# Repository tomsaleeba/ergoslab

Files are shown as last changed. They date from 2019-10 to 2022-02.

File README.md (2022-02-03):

> a columnar stagged keyboard that uses a combination of Cherry MX (or
> compatible) and Kailh choc switches to pack in a heap of thumb keys

*Update Dec 2020*: I've been using this keyboard full time (I'm a professional
software developer so it sees a lot of use) for a year now and I'm still in love
with it. If you're considering making one, I would call this design battle
proven now.

*Update Jan 2022*: Still using this full-time and loving it 💪.

- [What is this thing?](#what-is-this-thing)
- [Desgin choices:](#desgin-choices)
- [Build guide](#build-guide)
- [Gerbers](#gerbers)
- [Parts list](#parts-list)
  * [Parts you'll have to find yourself](#parts-youll-have-to-find-yourself)
  * [Parts available with PCB order](#parts-available-with-pcb-order)
- [Developers/contributing](#developerscontributing)
  * [Generating 3 layers of sandwich case](#generating-3-layers-of-sandwich-case)
  * [Generating gerbers](#generating-gerbers)
- [Credit for Kicad symbols/footprints](#credit-for-kicad-symbolsfootprints)
- [FAQ](#faq)

# What is this thing?
Before swapping to this keyboard, I had been using an ErgoDox Infinity and an EZ
as my daily drivers for quite a few years. I loved using them but I was looking
for something more compact and with more (easily accessible) thumb keys. There
are so many candidates
([here](https://docs.google.com/spreadsheets/d/19-rTWbp8SCKdZFByPZu3RT8NSF8vVddDe8WL6R6b1qQ/edit?usp=sharing),
[here](https://keebfol.io/), [here](https://golem.hu/boards/) and
[here](https://github.com/diimdeep/awesome-split-keyboards)) but none match
*exactly* what I want, so I decided build my own!

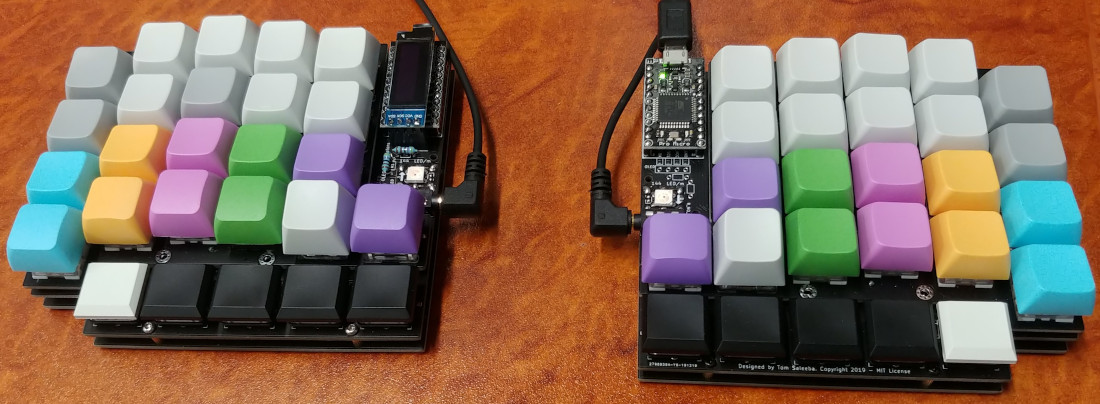
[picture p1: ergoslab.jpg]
ergoslab keyboard photo


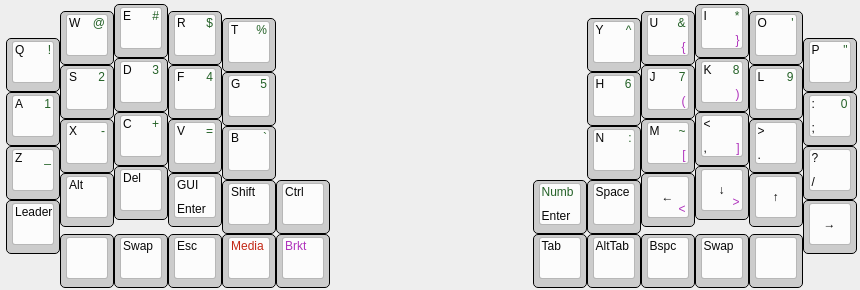
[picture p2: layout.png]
keyboard layout


# Desgin choices:
  - Kailh hotswap sockets for all the MX-style switches (choc are soldered in)
  - ErgoDox style ortho-columnar but with the extra little finger offset of the
      [Diverge 3](https://unikeyboard.io/product/diverge-3/)
  - Make all thumb keys easily accessible from the normal hand position
  - keys for vim-style arrows on the right hand, and directly below the home row
  - same plate design for both halves
  - compatible with QMK firmware, see [keyboard directory in QMK](https://github.com/qmk/qmk_firmware/tree/master/keyboards/ergoslab)
  - optional top LED for layer status ([example](./misc/layer-led-in-action.jpg))
  - optional underglow LEDs
  - minimise overall footprint by using internal standoffs (thanks for the idea
      [ErgoTravel](https://github.com/jpconstantineau/ErgoTravel))
  - use only 1U key caps to minimise size and because stabilisers are annoying
  - author a single "master" PCB and use a python script to generate the 3
      layers of the sandwich case. Makes life much easier to keep them all in
      sync. (See further down for more info)
  - support 5-pin/PCB mount switches

# Build guide
See the [guide here](./build-guide.md).

# Gerbers
See the [releases](https://github.com/tomsaleeba/ergoslab/releases) for this
GitHub repo for the generated Gerber files. You probably want the most recent
version.

If you need to generate your own gerbers, see [how to turn the master PCB into
the 3 generated PCBs](#generating-3-layers-of-sandwich-case) and then [how to
generate gerbers](#generating-gerbers).

# Parts list
## Parts you'll have to find yourself
  - 2x top PCBs (optional if you're happy with PCB mount; untested)
  - 2x middle PCBs (or 4x as they can also be used as the base)
  - 2x base PCBs (if you didn't order 4x middle)
  - 2x Pro Micros
  - 1x TRRS cable
  - 42x Cherry MX (or compatible) switches
  - 42x [Kailh hotswap PCB sockets](https://www.kailhswitch.com/mechanical-keyboard-switches/box-switches/mechanical-keyboard-switches-kailh-pcb-socket.html)
  - 10x Kailh choc switches
  - 42x 1U MX key caps
  - 10x 1U Kailh choc key caps
  - (optional) 2x WS2812 LED from a 144 LEDs/m strip, for layer status lights
  - (optional) more WS2812 LEDs, of any density per meter strip, for underglow
      lighting. 12x is probably a sane number but if you want to run them at
      lower power, you could probably use more.
  - 4x 15mm M2 standoffs (2 per side), for mounting the OLED/ProMicro acrylic cover
  - 8x M2 screws, between 4 and 8mm long, for the above standoffs
  - (optional) 1 or 2 OLED screens
  - 36x M2x4 screw (See Note1 and Note2) for mounting the middle/PCB layer to the base
      plate

**Note1**: the screw/bolt length depends on the height of the standoffs you get.
You want 1.6mm thick PCBs so make sure you don't have *too much* thread on your
screws.

**Note2**: it's highly recommended to get hex head/allen key/ISO7380 screws (see
image below). This is because a phillips head screwdriver probably won't fit
through the holes in the switch plate to tighten the screws on the middle/PCB
layer. You can always drill those holes a bit bigger or loctite the screws in
(so they won't need tighening) to workaround this. As you have hotswap sockets,
you may be able to remove the switches and pull the middle/PCB layer screws out
through the switch holes.  Beware: with 4mm long screws, I couldn't achieve
this, though it was very close.

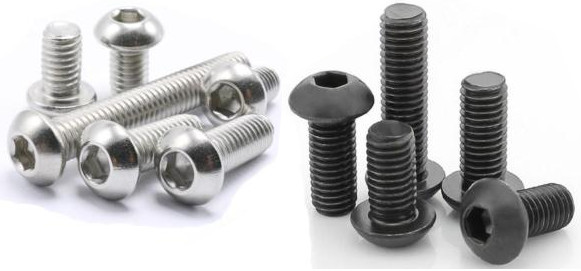
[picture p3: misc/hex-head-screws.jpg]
Photo of hex head screws


## Parts available with PCB order
These are the parts you can order from LCSC at the same time as having your PCBs
manufactured. The listed quantity is to assemble *both halves*.

| QTY |  Description |  LCSC Part No |
| :---: | :--- | :---: |
|0/2/4| 4.7KO (4701) ±1% (2 per OLED) |  [C58678](https://lcsc.com/product-detail/Metal-Film-Resistor-TH_4-7KR-4701-1_C58678.html) |
| 2  |  PJ-3200B-4A TRRS Connector |  [C136687](https://lcsc.com/product-detail/Audio-Video-Connectors_Korean-Hroparts-Elec-PJ-3200B-4A_C136687.html) |
| 2  |  Switch 5.2*5.2*1.5 reset switch |  [C92584](https://lcsc.com/product-detail/Tactile-Switches_Switch-5-2-5-2-1-5-250gf-Copper-head_C92584.html) |
| 2  |  2.54mm 1*40P round Female header |  [C9811](https://lcsc.com/product-detail/Female-Header_2-54mm-1-40P-round-Female-header_C9811.html) |
|0/1/2|  OLED Female header |  [C124413](https://lcsc.com/product-detail/Pin-Header-Female-Header_Ckmtw-Shenzhen-Cankemeng-C124413_C124413.html) |
| 52 |  1N4148 Switching Diode |  [C14516](https://lcsc.com/product-detail/Switching-Diode_1N4148_C14516.html) |
| 18 |  M2x6mm standoffs (See Note3) for middle/PCB layer to base plate mounting |  [M2x6](https://lcsc.com/product-detail/Studs_Made-in-China-Made-in-China-M2-6-3-5_C193468.html) |

**Note3**: the standoffs between the middle/PCB layer and the base plate can be
quite small, probably as small as 3mm. The problem with that is making sure the
bolts engage the threads enough. Feel free to experiment with getting a super
slim keyboard. Perhaps use a long bolt, a threadless spacer and a nut?

# Developers/contributing
Contributions are welcome. I'm not selling these keyboards and I already have
two for myself so I can't afford to manfacture more PCBs to test changes. If you
make changes to the PCB design, ideally you would confirm it all works by
manufacturing your own PCBs.

Steps for contributing:

1. if it's a non-trival change, consider opening an issue on this repo to talk
   about the change before spending effort
1. fork this repo
1. make your changes
1. if you made a change to the PCB, you need to [regenerate the 3 seperate
   generated PCBs](#generating-3-layers-of-sandwich-case)
1. send a pull request

## Generating 3 layers of sandwich case
We edit a single PCB file that contains the information required to generate all
3 layers (switch plate, circuitry, base) of a sandwich case keyboard. Keeping it
all in one file ensures that things like mounting holes always stay lined up.

There is some magic in the settings of items on the PCB to indicate what layer
they belong on. Read the code for the specifics but as a general guide:
  - we use Eco1.User as the templates for edge cuts that only appear on some
      layers
  - the width of the drawing lines are slightly different so we can determine
      which belongs on each layer
  - the thickness of text is slightly different so we can determine which
      belongs on each layer

You *must* have Kicad installed in your system. Doing this makes the `pcbnew`
python module available. Make sure you don't have any virtualenv, etc activated
as you need to be using you system-wide python. Check for the module by running
the following in the python REPL:

```python
import pcbnew
```

Now you can regenerate the PCBs with:

```bash
python ./generate_pcbs.py
```

Normally keeping generated things in source control is not a good idea but in
the interest of keeping things easy, we include the generated PCBs.

## Generating gerbers
Using KiCad 5.1.4, here's the settings to generate gerbers.

Plot settings (should be the defaults):
```
Plot format: Gerber
Included layers:
  F.Cu
  B.Cu
  F.Paste
  B.Paste
  F.SilkS
  B.SilkS
  F.Mask
  B.Mask
  Edge.Cuts
Plot foorprint values: yes
Plot footprint references: yes
Exclude PCB edge layer from other layers: yes
Exclude pads from silkscreen: yes
Default line width: 0.1mm
Coordinate format: 4.6, unit mm
```

Drill settings:
```
Drill File Format: Excellon
Mirror Y axis: no
Minimal header: no
PTH and NPTH in single file: no
Oval Holes Drill Mode: Use alternate drill mode
Map File Format: PostScript
Drill Origin: Absolute
Drill Units: Inches
Zeros Format: Suppress leading zeros
```

The fix for the JLCPCB PTH layer error was to change the [oval hole drill
mode](https://forum.kicad.info/t/jlcpcb-gives-me-warnings-on-drill-and-edge-cuts/17565/25).

# Credit for Kicad symbols/footprints
- [Kailh reversible footprints](https://github.com/daprice/keyswitches.pretty/blob/f89ef994a51043281f3fa6dfb4a93d8e4bebdbd1/Kailh_socket_reversible.kicad_mod) ([CC BY-SA](https://github.com/daprice/keyswitches.pretty/blob/f89ef994a51043281f3fa6dfb4a93d8e4bebdbd1/LICENSE.md))
- [P-08073 TACT reset switch footprint](https://github.com/kata0510/minisplit/blob/5fc4b23/minisplit-footprint.pretty/TACT_SWITCH_TVBP06.kicad_mod) ([MIT License](https://github.com/kata0510/minisplit/blob/5fc4b233df8120694ade5a3a812970439e8fc585/LICENSE))
- [symbols: TRRS jack, resistor](https://github.com/MakotoKurauchi/helix/tree/master/PCB/beta) (exported from schematic) ([MIT License](https://github.com/MakotoKurauchi/helix/blob/master/LICENSE))
- [LED symbol](https://github.com/tmk/kicad_lib_tmk) (no license)
- 2.54mm pin headers and diode footprints from built in Kicad library
- [footprints: 4 pin TACT reset, ProMicro, diode](https://github.com/jpconstantineau/ErgoTravel/tree/d443bf4/Library/footprints.pretty) ([MIT License](https://github.com/jpconstantineau/ErgoTravel/blob/master/LICENSE))

# FAQ
**How portable is it?**
It weighs 360grams (180grams for each half) with cheap DSA plastic keycaps. It
measures 115mm x 102mm and with 6mm standoffs, it's 16mm to the top of the
switch plate or 31mm to the top of DSA keycaps, including the height of rubber
bump-ons. I'll let you decide how portable you think that is but it was designed
to be portable.

**Is I2C between the halves supported?**
Sort of. The OLED screens use I2C so you won't be able to use them. Also there's
no solder jumpers so you'll have to jump some wires between the OLED header
SDA/SCL pins and the SLAVE_LED pin/data pin on the unused TRRS jack. This isn't
an intended use but you can certainly hack it, check the schematic for details.

**What happened to a single PCB that works as all 3 layers?**
Originally I tried to make one PCB design that works as all 3 layers of a
sandwich design: base, PCB and switch plate. The idea was taken from
[for-split-keyboard](https://github.com/peej/for-split-keyboard) and
[mitosis](https://www.reddit.com/r/MechanicalKeyboards/comments/66588f/wireless_split_qmk_mitosis/).
I failed because I wanted to have minimal post-manufacture cutting by hand and
JLCPCB kept rejecting my desgins as they didn't have strong enough supports to
hold the PCB together though the whole manufacture process. So now we have
"master" PCB design and use a python script to generate the PCBs for each layer
from that master.

**Do you have keyboard-layout-editor source?**\
Yes. Either [this file](./layout.kle) in this repo or here's a (hopefully up to date)
<a href="http://www.keyboard-layout-editor.com/##@@_x:3&t=#000000%0A%0A#115219;&=E%0A%0A#&_x:9.75&t=#000000%0A%0A#115219%0A#9914a6;&=I%0A%0A*%0A%7D;&@_y:-0.875&x:2&t=#000000%0A%0A#115219;&=W%0A%0A/@&_x:1;&=R%0A%0A$&_x:7.75&t=#000000%0A%0A#115219%0A#9914a6;&=U%0A%0A/&%0A%7B&_x:1&t=#000000%0A%0A#115219;&=O%0A%0A';&@_y:-0.875&x:5;&=T%0A%0A%25&_x:5.75;&=Y%0A%0A%5E;&@_y:-0.625&x:1;&=Q%0A%0A!&_x:13.75;&=P%0A%0A%22;&@_y:-0.625&x:3;&=D%0A%0A3&_x:9.75&t=#000000%0A%0A#115219%0A#9914a6;&=K%0A%0A8%0A);&@_y:-0.875&x:2&t=#000000%0A%0A#115219;&=S%0A%0A2&_x:1;&=F%0A%0A4&_x:7.75&t=#000000%0A%0A#115219%0A#9914a6;&=J%0A%0A7%0A(&_x:1&t=#000000%0A%0A#115219;&=L%0A%0A9;&@_y:-0.875&x:5;&=G%0A%0A5&_x:5.75;&=H%0A%0A6;&@_y:-0.625&x:1;&=A%0A%0A1&_x:13.75;&=/:%0A/;%0A0;&@_y:-0.625&x:3&t=#000000%0A#0b458a%0A#115219;&=C%0A%0A+&_x:9.75&t=#000000%0A%0A#115219%0A#9914a6;&=%3C%0A,%0A%0A%5D;&@_y:-0.875&x:2&t=#000000%0A#0b458a%0A#115219;&=X%0A%0A-&_x:1;&=V%0A%0A/=&_x:7.75&t=#000000%0A%0A#115219%0A#9914a6;&=M%0A%0A~%0A%5B&_x:1&t=#000000;&=%3E%0A.;&@_y:-0.875&x:5&t=#000000%0A%0A#115219;&=B%0A%0A%60&_x:5.75;&=N%0A%0A/:;&@_y:-0.625&x:1&t=#000000%0A#0b458a%0A#115219;&=Z%0A%0A/_&_x:13.75&t=#000000;&=?%0A//;&@_y:-0.625&x:3;&=Del&_x:9.75&t=#000000%0A%0A%0A#9914a6;&=%0A%0A%0A%3E%0A%0A%0A%0A%0A%0A%E2%86%93;&@_y:-0.875&x:2&t=#000000;&=Alt&_x:1;&=GUI%0AEnter&_x:7.75&t=#000000%0A%0A%0A#9914a6;&=%0A%0A%0A%3C%0A%0A%0A%0A%0A%0A%E2%86%90&_x:1&t=#000000&a:7;&=%E2%86%91;&@_y:-0.875&x:5&a:4;&=Shift&=Ctrl&_x:3.75&t=#115219;&=Numb%0AEnter&_t=#000000;&=Space;&@_y:-0.625&x:1;&=Leader&_x:13.75&a:7;&=%E2%86%92;&@_y:-0.375&x:2;&=&_a:4;&=Swap&_t=#000000%0A#0b458a;&=Esc&_t=#ab0202;&=Media&_t=#9914a6;&=Brkt&_x:3.75&t=#000000;&=Tab&=AltTab&=Bspc&=Swap&_a:7;&=">permalink</a>

**Do you have a vector of the right hand "plate"?**\
Yep, see [misc/ergoslab-right.svg](misc/ergoslab-right.svg).

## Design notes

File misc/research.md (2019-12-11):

## Answered questions
  1. can I get the same "only flash master" behaviour as the Ergodox EZ by
     using a [MCP23018-E/SP I/O expander](https://www.ergodox.io/#electronics)
     on the slave side? Yes, but it's not worth it as it'll be slow.
     [link](https://www.reddit.com/r/olkb/comments/bdchr5/hardware_options/el2b9s9/)
     [link](https://www.reddit.com/r/olkb/comments/a8y8mv/help_using_an_io_expander_with_qmk/ecro8p5/)
  1. do we need [pull up
     resistors](https://beta.docs.qmk.fm/features/feature_split_keyboard#required-hardware)
     for communication between the two halves? Only if you want to use I2C to
     communicate between the halves. If you're happy to use serial, then you
     don't use the resistors.
  1. do we need a blank space to rest thumbs? No, resting them on a switch works
     fine.
  1. from top of switch plate, we need 8.3mm for Kailh Box switches to clear the
     base plate. So including a 1.6mm thick base PCB and 1.75mm thick nut, we
     need at least 11.65mm long bolt that can sandwhich everything.
     Alternatively, we need at least 6.7mm of space *between* the switch and
     base plates.

## Facts
- MX switches are 5mm deep, Kailh choc are 2.35mm so the choc row should drop by
  2.65mm. The top of the choc switches will be ~5mm above the top of the
  switchplate for the MX switches.
- WS2812 strips are driven from any old pin, they don't use I2C
- ErgoDox style columnar staggered: 0, +1/4U (4.75mm), +3/8U (7.125mm), +1/4U
  (4.75mm), +1/8U (2.375mm)
- stabilising 4th/5th legs on Gateron switch: 1.575mm (as measured with
    micrometer)

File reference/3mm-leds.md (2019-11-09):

Bought from https://www.ebay.com.au/itm/Ultra-Bright-Clear-LEDs-3mm-or-5mm-Red-Yellow-Blue-Green-White-or-Mixed/192224975067

# 3mm Specifications.

Colour | Typical Voltage | Typical Current | Typical Brightness | Resistor @ 5V
-------|-----------------|-----------------|--------------------|--------------
Red    | 1.8-2.3V        | 20mA            | 4000-5000 mcd      | 82 - 100ohm
Yellow | 1.8-2.3V        | 20mA            | 2000-3000 mcd      | 82 - 100ohm
Blue   | 3.2-3.4V        | 20mA            | 3000-5000 mcd      | 150 - 180ohm
Green  | 3.2-3.4V        | 20mA            | 12000-20000 mcd    | 150 - 180ohm
White  | 3.2-3.4V        | 20mA            | 6000-8000 mcd      | 150 - 180ohm

Resistors calculated with http://led.linear1.org/1led.wiz

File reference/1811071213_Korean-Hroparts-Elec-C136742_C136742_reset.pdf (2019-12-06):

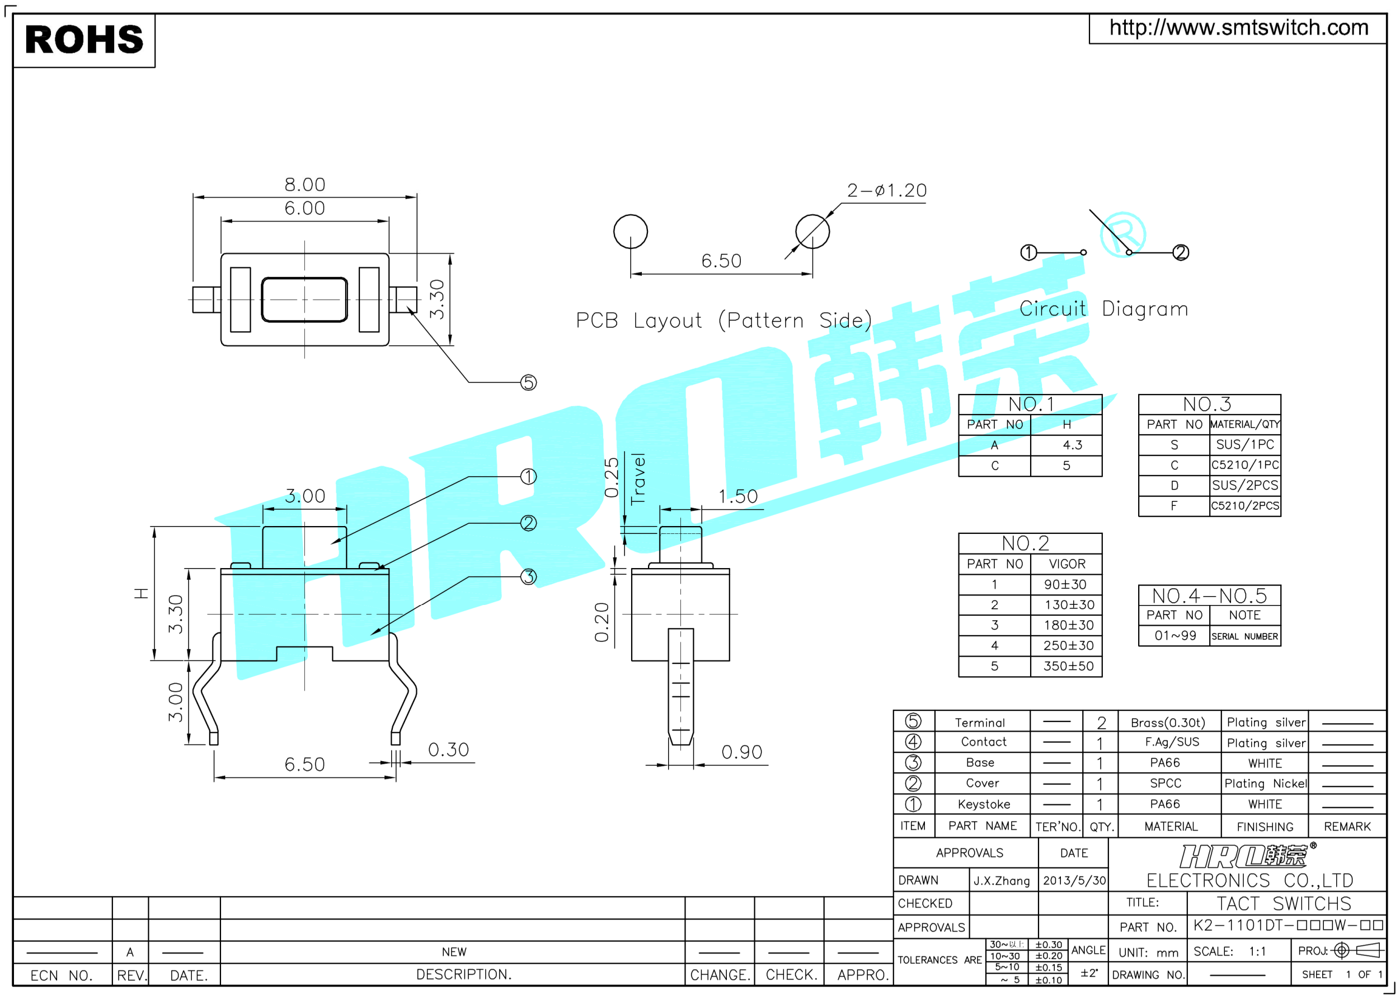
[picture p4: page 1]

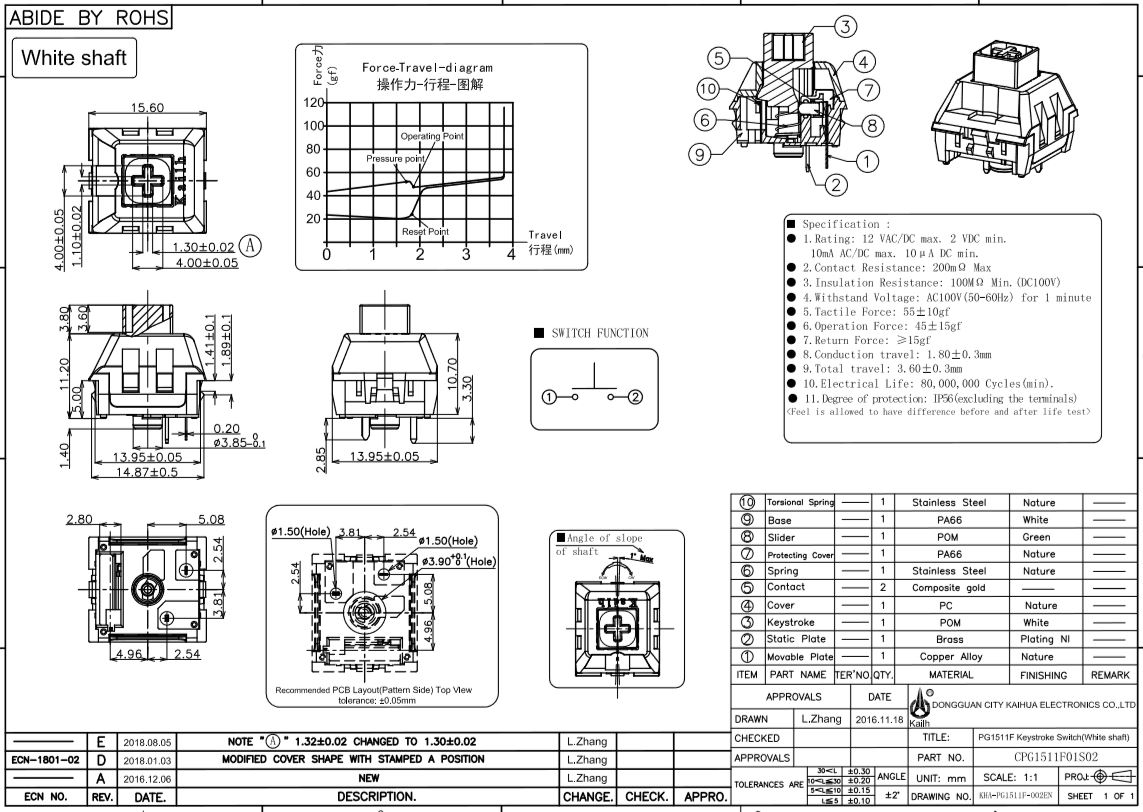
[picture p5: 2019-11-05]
reference/kailh-box-switch-specifications-NEW.jpg

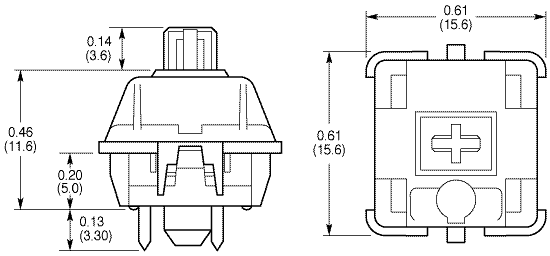
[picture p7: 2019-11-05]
reference/cherry-mx-specs.gif

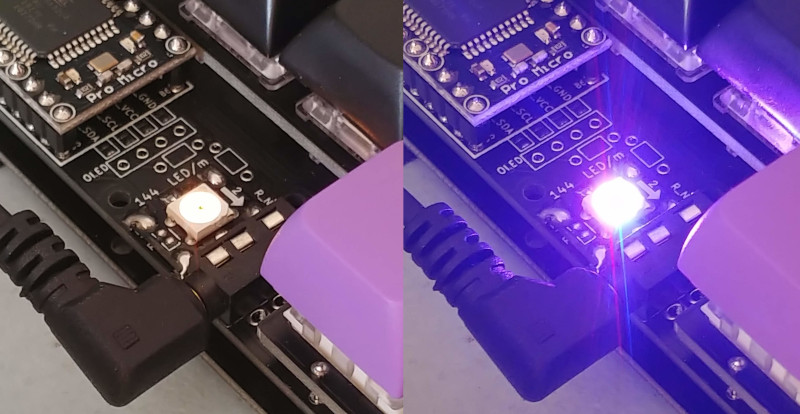
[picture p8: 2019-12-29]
misc/layer-led-in-action.jpg

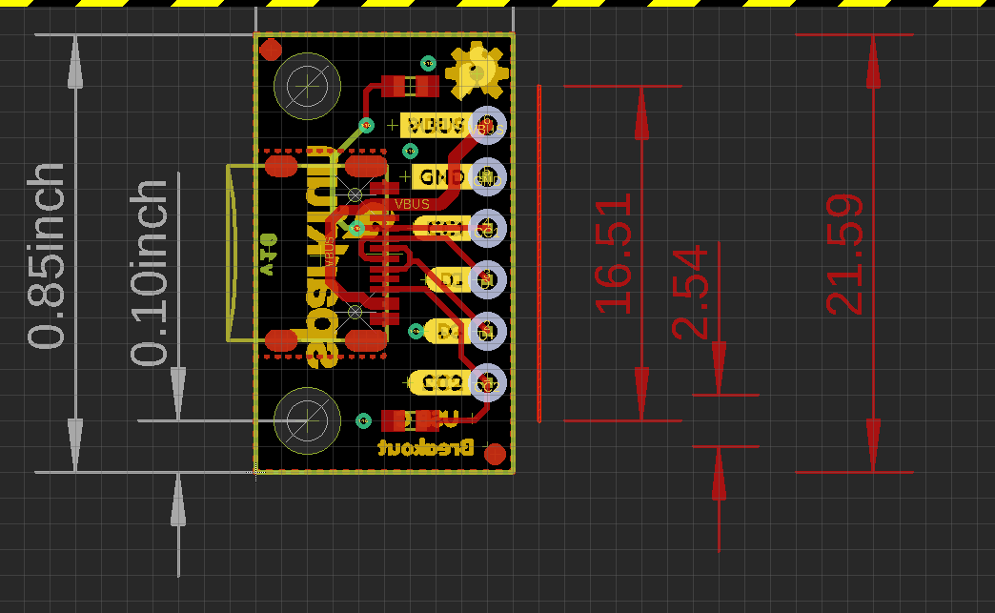
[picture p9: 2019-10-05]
misc/usb-c-breakout.png

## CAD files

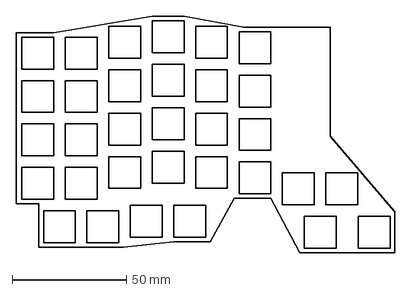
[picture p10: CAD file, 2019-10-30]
misc/test-layouts/helix-stagger/switchplate.dxf
166.2 x 103.7 mm

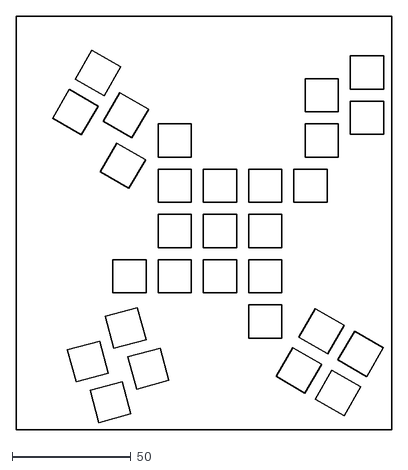
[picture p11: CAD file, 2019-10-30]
misc/test-layouts/throwing-star-thumb-tester/switchplate.dxf
157.9 x 174.3

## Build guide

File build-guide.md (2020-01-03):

# Steps
1. Install diodes. Place them over the silk screen markers so you don't cover
   the pads for the hotswap sockets. This means both sides will be the same and
   yes, you'll have diodes on the top and bottom of both halves.
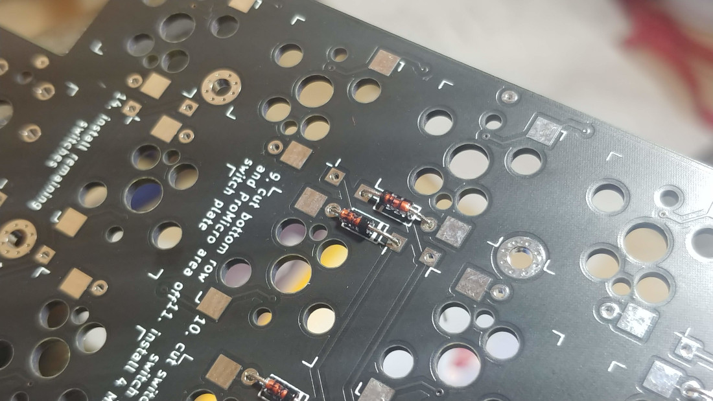
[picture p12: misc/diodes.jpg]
diodes
    
1. trim the diode legs but keep them as we'll need them later for the ProMicro
   pins (into the sockets) and for bracing the switchplate to the middle/PCB
   layer.
1. Install the reset switch. First tin one of the pads
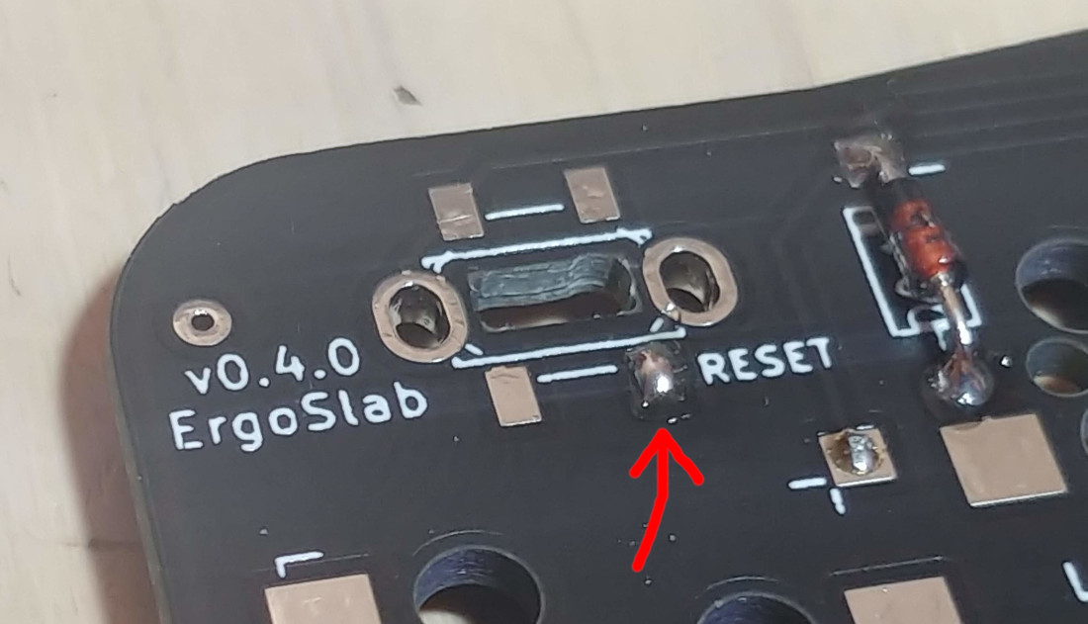
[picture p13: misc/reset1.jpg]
reset switch tinned pad
    
1. then reflow the tinned pad and solder a leg of the reset switch
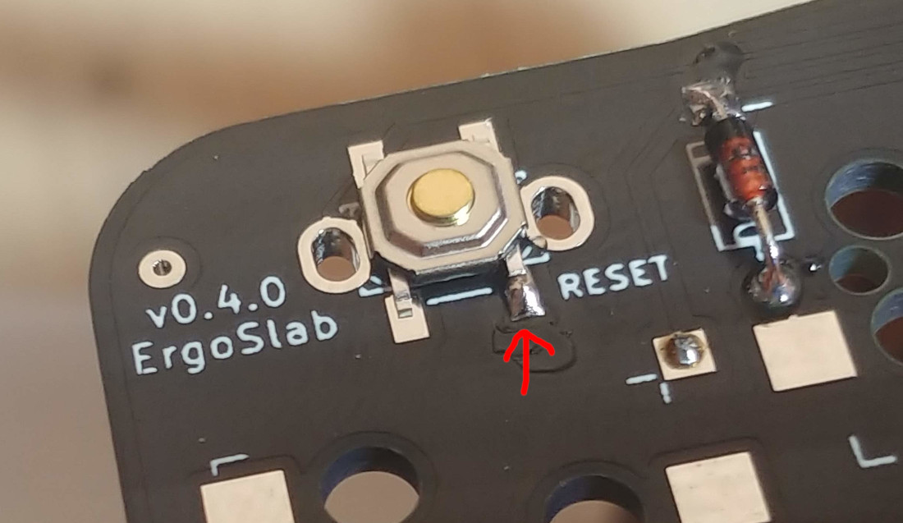
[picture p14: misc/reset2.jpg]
reset switch reflow leg
    
1. now you can solder the other legs
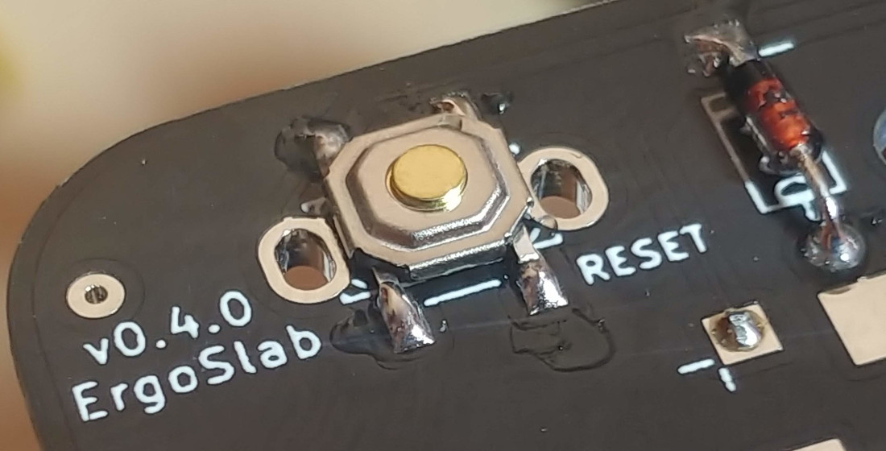
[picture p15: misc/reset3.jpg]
reset switch other legs
    
1. If you're using an LED on the top, install that now. Do the same trick as the
   reset switch where you tin one pad, reflow, then solder the other pads. The
   144 LEDs/m don't seem to have space to label the pads but on mine, the edge
   with the arrow is the GND.
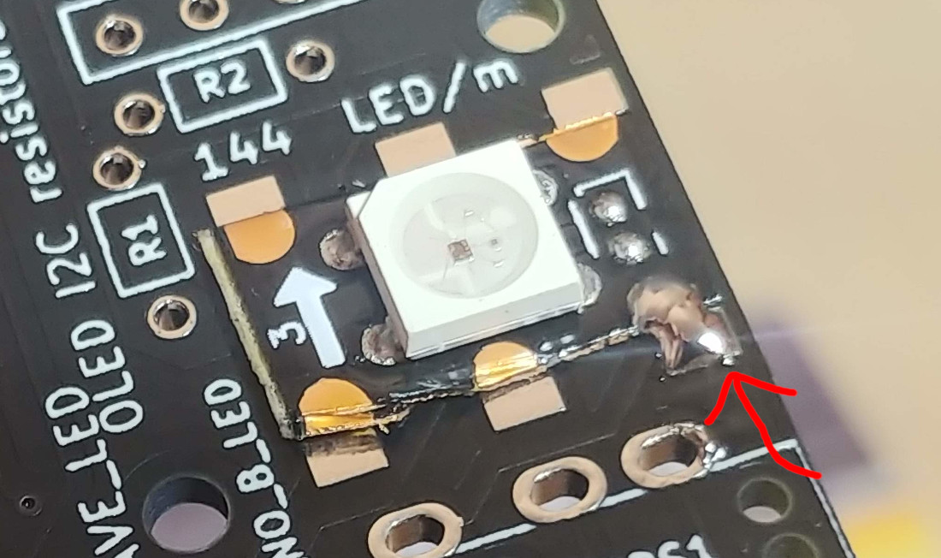
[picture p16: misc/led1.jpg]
LED first pad
    
   If you want LEDs on the bottom but **not** on the top, solder the top bypass
   in the middle of the WS2812 pad, marked with `{L|R}_NO_F_LED`.
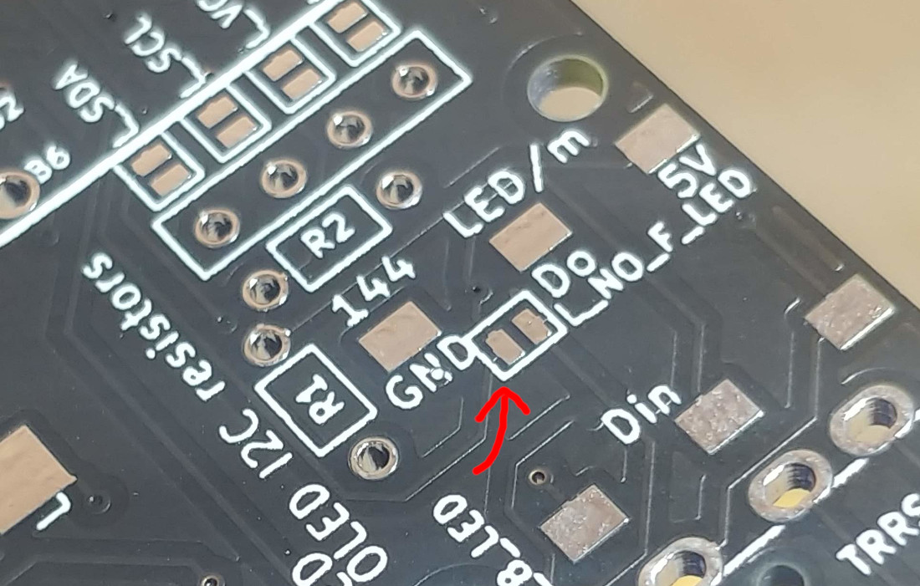
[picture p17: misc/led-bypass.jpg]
LED bypass jumper
    
1. Install the TRRS connector on the *top* of the PCB
1. If you're **NOT** using an LED strip on the bottom, solder the bypass marked
   `{L|R}_NO_B_LED`. The bypass jumper is on the top of the PCB and when
   soldered will connect the `Do` from the top LED to PIN on the TRRS connector
   that sends the LED data to the other half. This will appear on the
   `SLAVE_LED` pin on the slave.
1. (optional, for OLED) solder the jumpers on the **top** of the PCB. It can be
   a bit fiddly to get the solder to jump the gap. I've found the best way is to
   make sure you heat both the pads properly (have the iron in contact for a few
   seconds) and lift the iron up when you're done. If you drag the iron
   sideways, the solder doesn't seem to want to jump the gap. If you can't get
   the solder to jump the gap, like this (don't install the header first, like I
   did. That was a mistake):
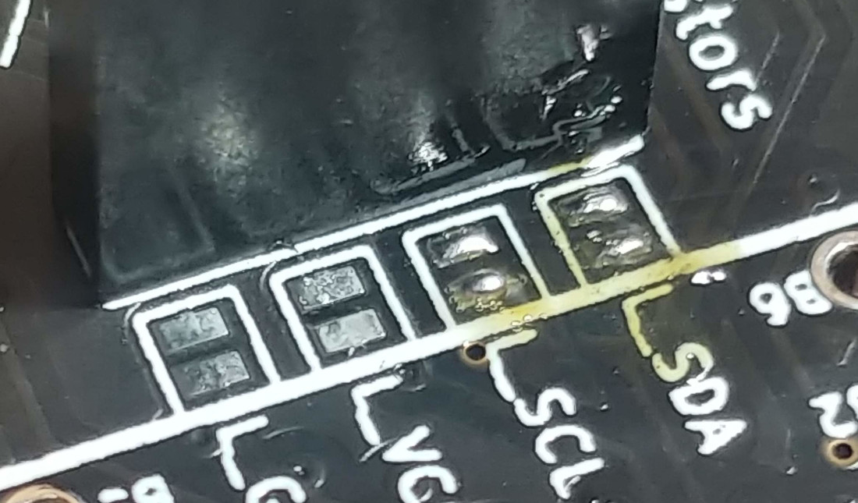
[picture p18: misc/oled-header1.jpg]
OLED jumper fail
    
   ...then use a small piece of diode leg to bridge the gap. I used a longer
   piece then trimmed it after soldering.
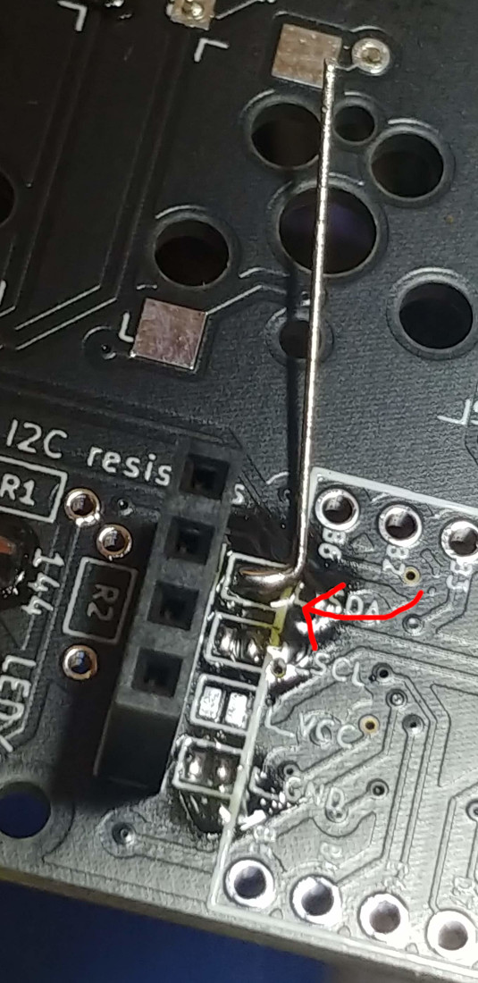
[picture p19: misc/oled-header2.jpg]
OLED bridge
    <br />
   All four jumpers should be soldered at the end:<br />
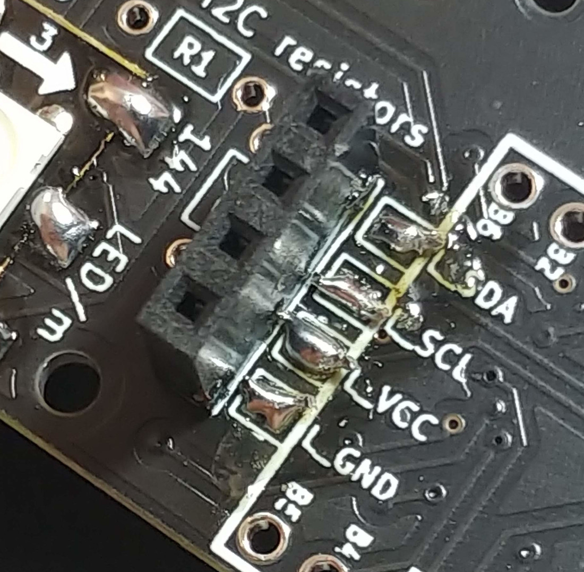
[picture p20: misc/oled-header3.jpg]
OLED header done
    
1. (optional, for OLED) install the I2C resistors
1. (optional, for OLED) install the header. If you only want to run one OLED, I
   suggest putting it on the left as that ProMicro mounts upside down which
   lets the OLED mount lower.
1. Install the 11 standoffs. Make sure you use cap screws (allen key head) on
   the top of the middle layer. This is so you can always tighten them after
   assembly. A phillips head screwdriver probably won't fit through the hole in
   the switchplate. (Yep, I forgot two diodes in these photos.)
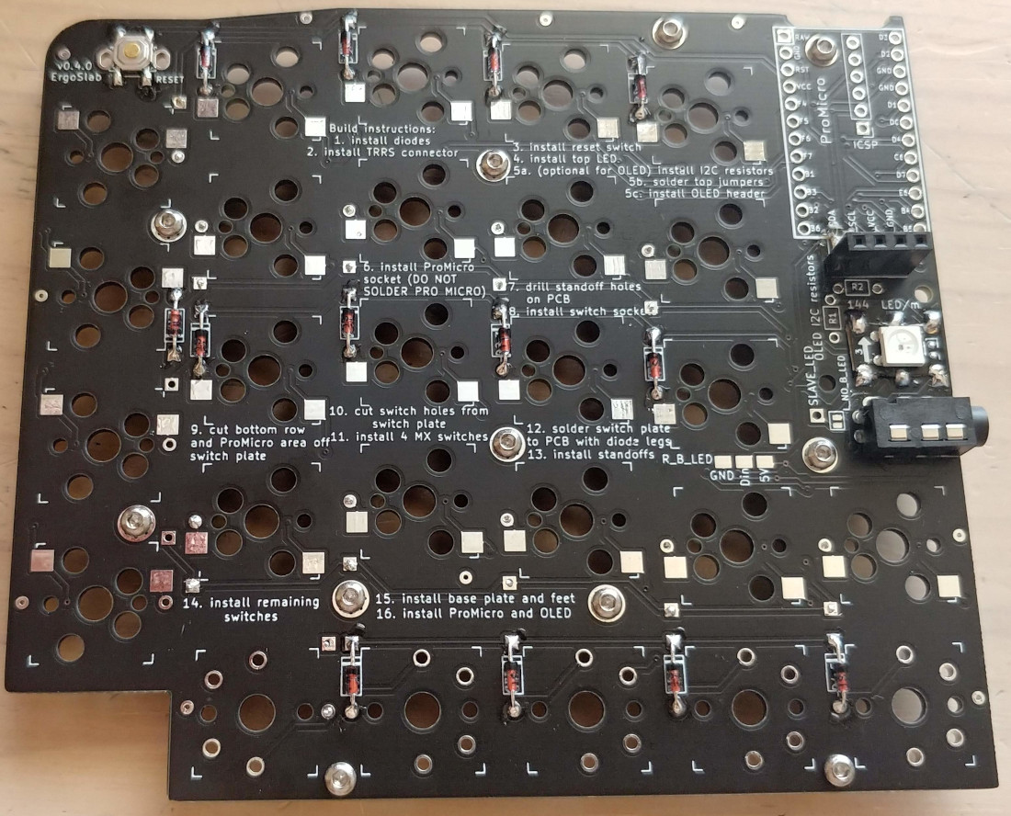
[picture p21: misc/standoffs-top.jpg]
standoffs from top
    
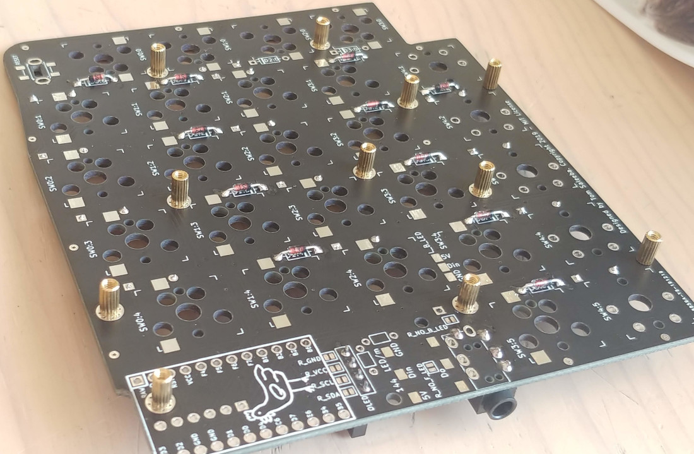
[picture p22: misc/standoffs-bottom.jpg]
standoffs from bottom
    
1. Install the ProMicro sockets. Do not solder the ProMicro directly to the PCB.
   It's best to sit them in the holes and hold them in with some tape. Then
   solder one pin and you can remove the tape. Now you can reflow the single
   soldered pin and make sure the socket is flat and lined up. If you use your
   finger, don't put it over the pin you're heating, it will get hot.
1. Install 4 MX switches, one in each corner of the switch plate. Mount the
   switch plate over the PCB/middle layer.
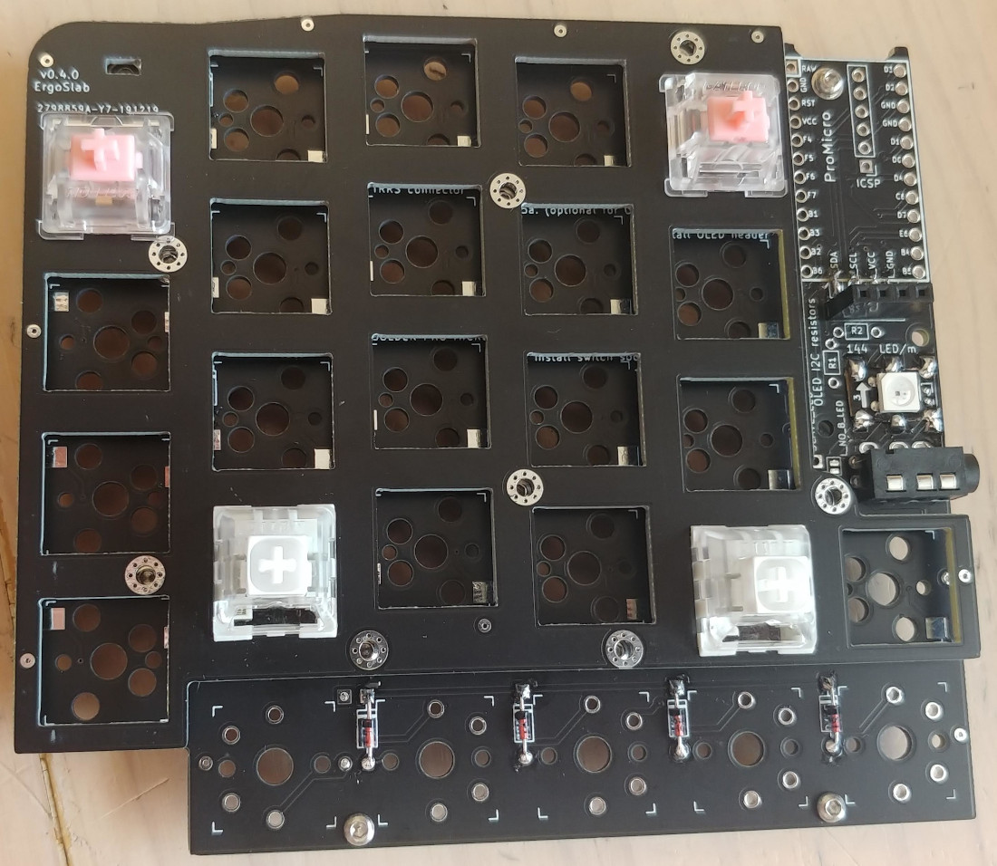
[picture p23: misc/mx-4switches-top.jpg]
mx switches from top
    
   When you install the switches, make sure the legs go through the holes and do
   NOT have the visible solder pads next to them. Here's a view from the
   *bottom* that shows why we use those holes; so the pins line up with the pads
   on the bottom side.
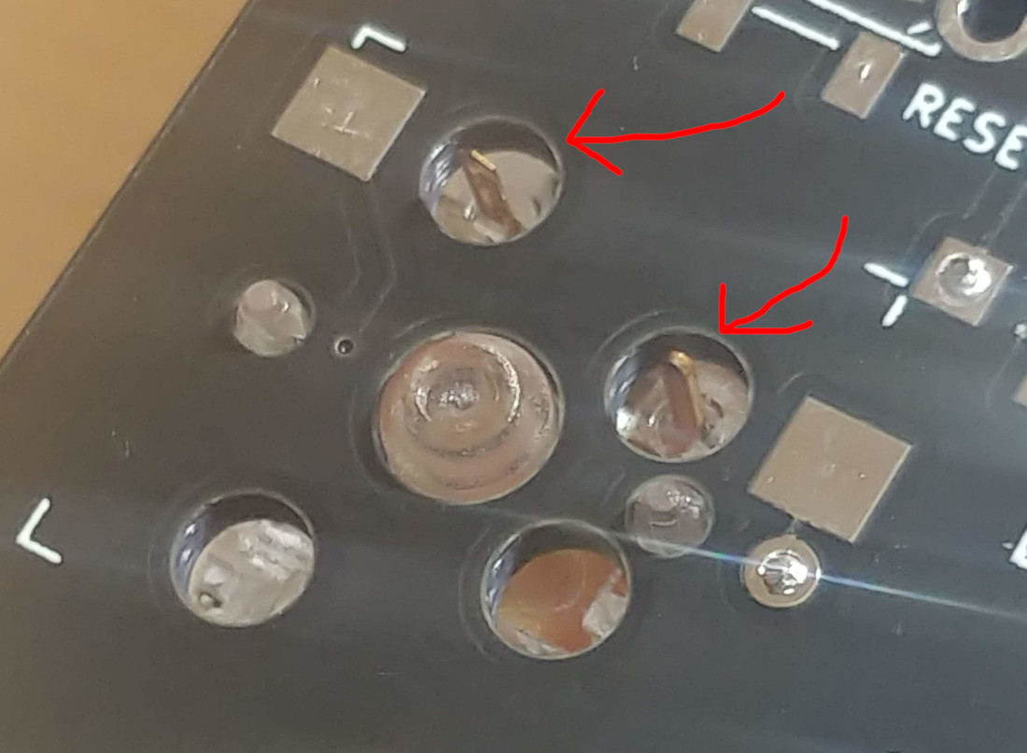
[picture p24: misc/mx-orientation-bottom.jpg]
mx switches from bottom
    
1. Now we need to brace the switchplate to the middle/PCB layer. As this
   keyboard uses hotswap sockets, we don't want the switch plate to move around
   when we're changing switches. You can always cut or desolder these later to
   pull the switchplate off. Drop diode legs through all the switchplate brace
   holes so they sit on the desk.
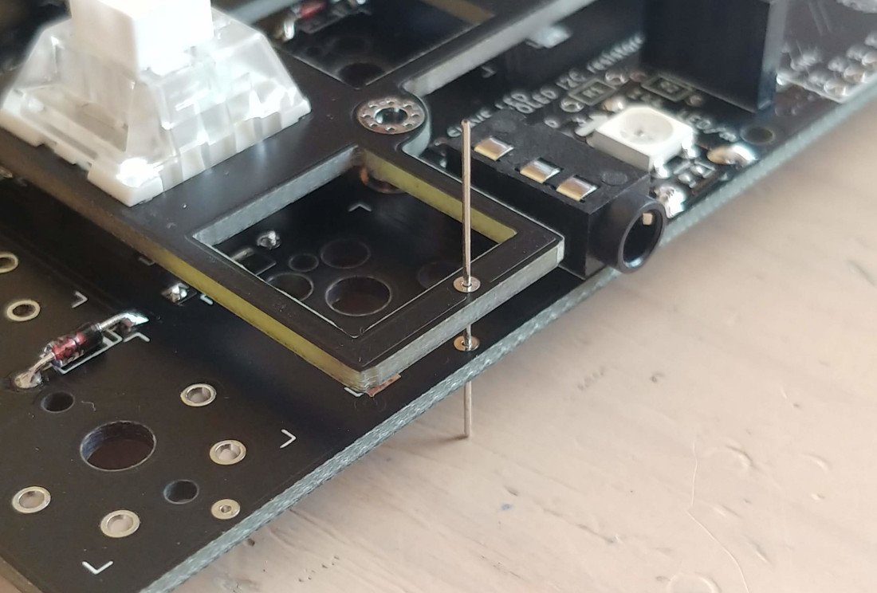
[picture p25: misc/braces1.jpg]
braces sitting in holes
    
1. Solder the tops of the braces and trim the excess
1. Make sure the switches are completely seated and the switchplate is pulled up
   to the correct height. We're about to attach the switchplate to the
   PCB/middle layer. Flip over and solder the bottom of the braces and trim the
   excess.
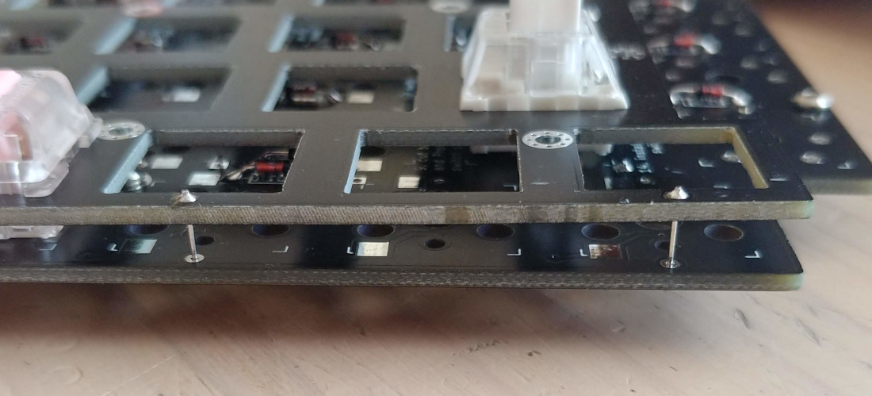
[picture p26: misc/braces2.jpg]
braces soldered
    
1. Install the rest of the MX switches, paying attention to install them the
   correct way. They don't all go the same way.
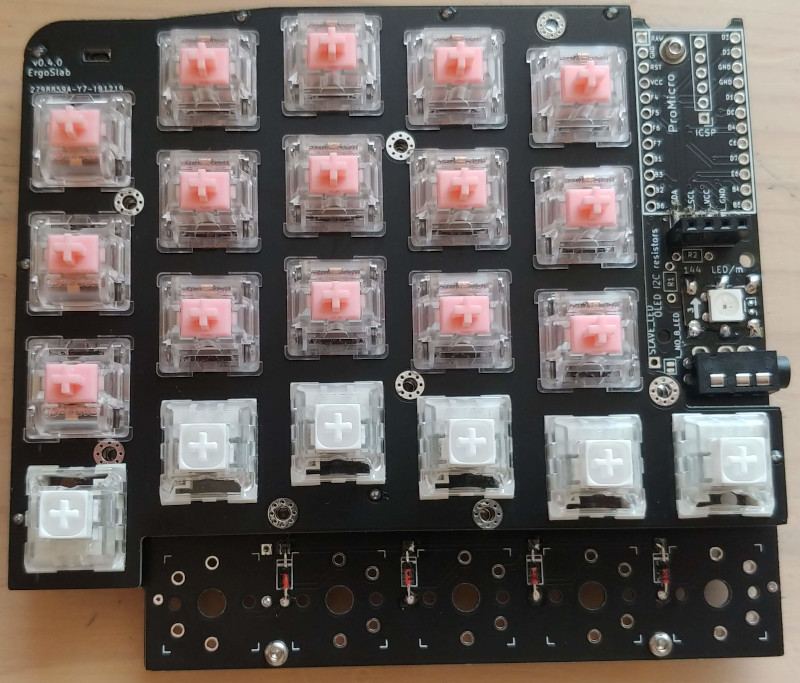
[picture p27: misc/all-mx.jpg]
all MX switches installed
    
1. Install the switch hotswap sockets. Again, not all of them are the same
   orientation so pay attention.
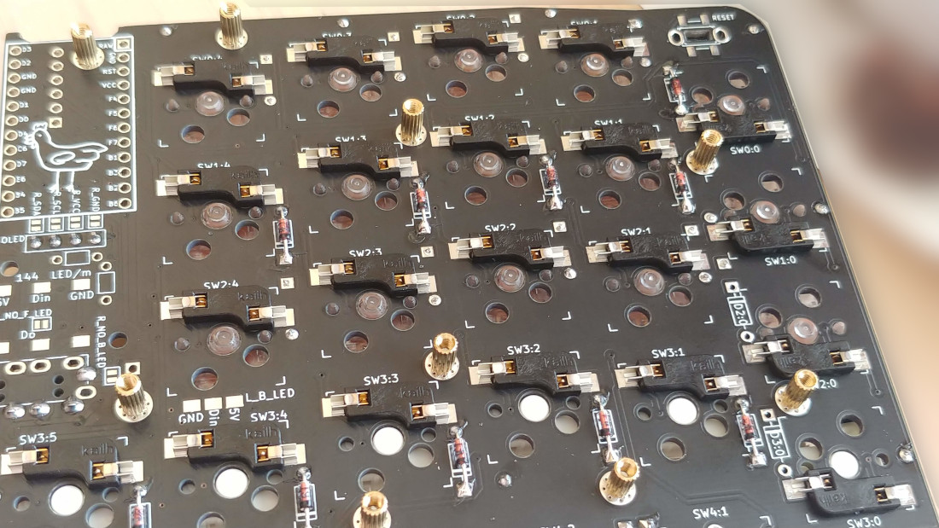
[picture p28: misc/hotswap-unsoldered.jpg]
hotswap sockets
    
1. Solder all the hotswap sockets
1. Install the Choc switches and solder
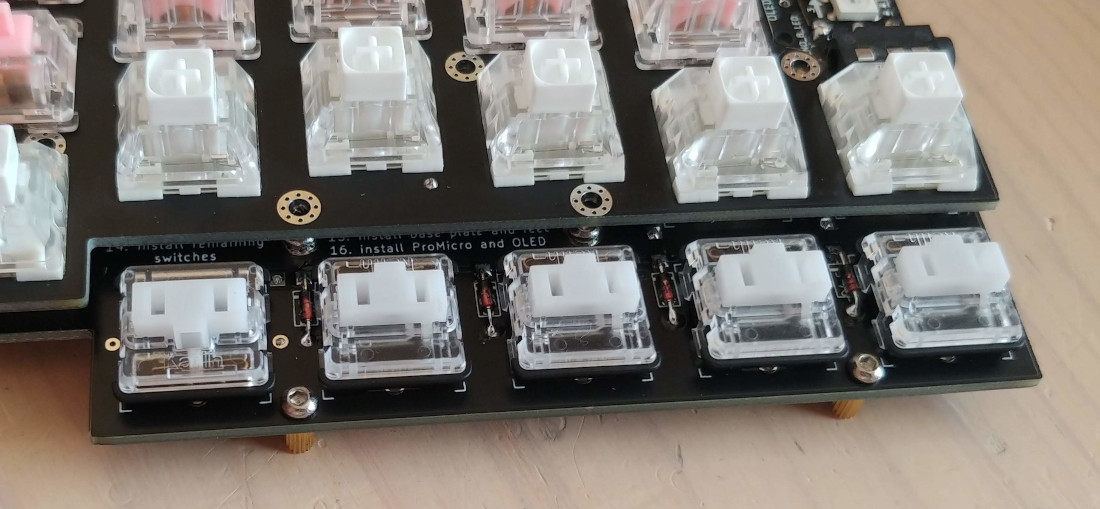
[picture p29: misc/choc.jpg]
choc switches
    
1. Install the ProMicro using left over diode legs. Insert them into the
   sockets, making sure they go all the way in. Then solder them to the ProMicro
   and trim the excess.
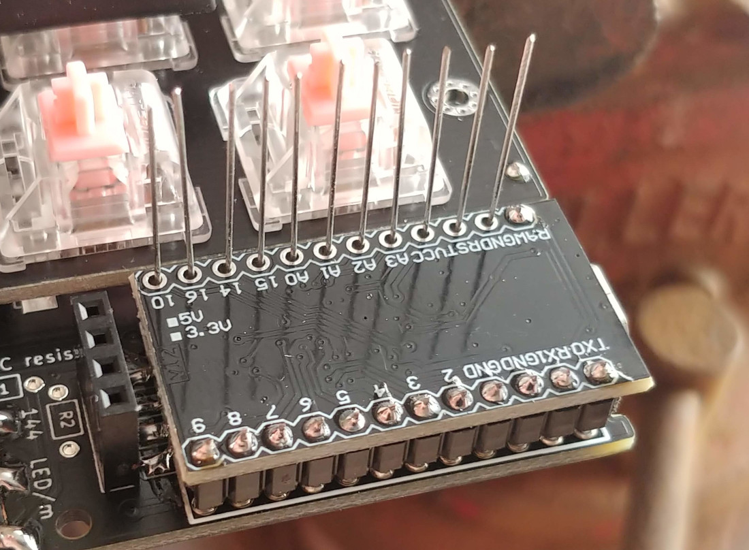
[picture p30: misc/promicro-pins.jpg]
promicro pins
    
1. Install the base plate
1. (optional, for OLED) Install the OLED screen
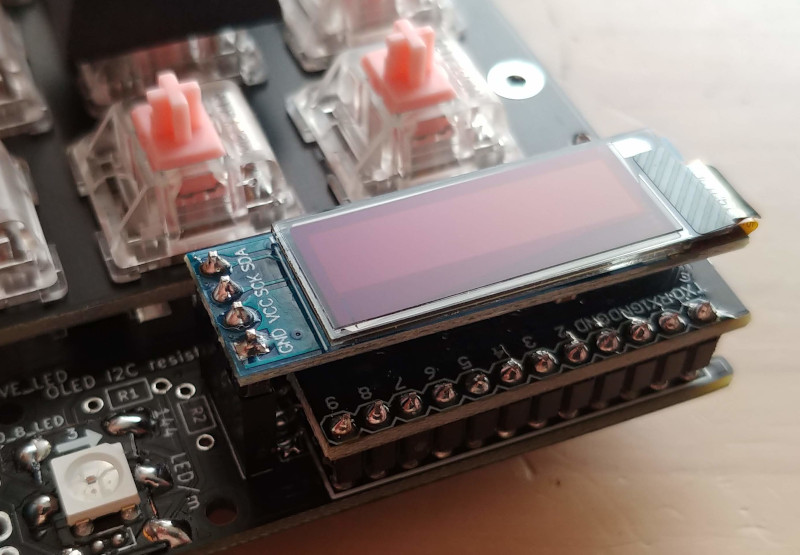
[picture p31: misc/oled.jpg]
oled screen
    
1. Repeat for the other half
1. flash firmware to both halves

# Option: floating middle PCB
If you want to, you can use a 4.5mm drill bit to drill out the M2 mounting holes
on the PCB (middle layer of sandwich). This means your standoffs are attached
between the base and switch plate, passing right through the middle layer.

There are M2 mounting holes to support the Choc row of switches. If you cannot
find standoffs the correct height, there is another option to support these
switches. There are two small plated through holes; one at either end of the
row of Choc switches. Solder up the holes in the base layer and solder a diode
leg into the hole on the PCB/middle layer. The diode leg will then rest on the
solder on the base plate and provide support.

# Option: join underglow LEDs between halves
QMK is meant to be able to directly control the backlight LEDs on the slave side of the
keyboard. At the time of writing, I couldn't get this to work. So if you want to
run underglow on both sides, or if you want all your underglow LEDs in one long
chain, you can link them together.

To do this, one the master side, you need to use a piece of wire to connect the
`Do` (output) from the LED strip to the `SLAVE_LED` plate through hole connector
just below the ProMicro.

Then, on the slave, you connect the `SLAVE_LED` pin to the `Din` (input) of your
LED strip. If you want to also run the top LED on the slave, you'll have to wire
that up yourself.

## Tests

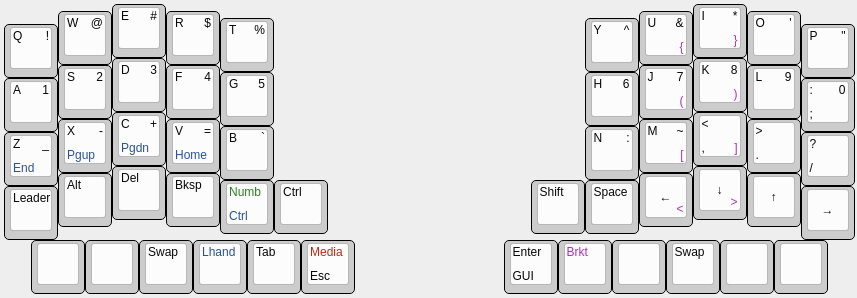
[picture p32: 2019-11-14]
misc/test-layouts/helix-stagger-5col/layout.png

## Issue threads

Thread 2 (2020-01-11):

Pcb holes

GeneralMidi, 2020-01-11:
Hi, I'm very interested in trying your build, but thought I would try the ergodox first. I uploaded the Gerber files to jlcpcb and I got en email back saying the holes are the same size as the pads. As a complete noob, I thought I'd ask you! Is it really as simple as "use alternate drill mode"?
Cheers
Luke

GeneralMidi, 2020-01-11:
All good. Apparently it's fine

tomsaleeba, 2020-01-11:
Hi @GeneralMidi , I'm excited you're giving my keyboard a try. Did you use the gerbers from the releases page here on GitHub or generate them yourself? As I mention on the release for v1.0.0, I haven't had them manufactured so if there's something wrong with the gerbers, I'm eager to get the problem fixed.

GeneralMidi, 2020-01-12:
Nah mate, it was for the ergodox. See here:

https://www.reddit.com/r/ergodox/comments/en8al2/jlcpcb_issue_with_drill_holes/

Closed 2020-01-11.

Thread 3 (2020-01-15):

Switchplate braces obstruct switch remove tool

tomsaleeba, 2020-01-15:
When looking at the left hand, the two brace holes in the bottom-left and the one in the bottom right of the *switch plate* (not the ones for the choc row) are placed next to switches. The switch removal tool needs to engage with the middle of the switch and this is where the brace holes are. It's still possible to use a switch removal tool as of v1.0.0 but it will be a better user experience if these holes are moved so they don't line up with the middle of switches.

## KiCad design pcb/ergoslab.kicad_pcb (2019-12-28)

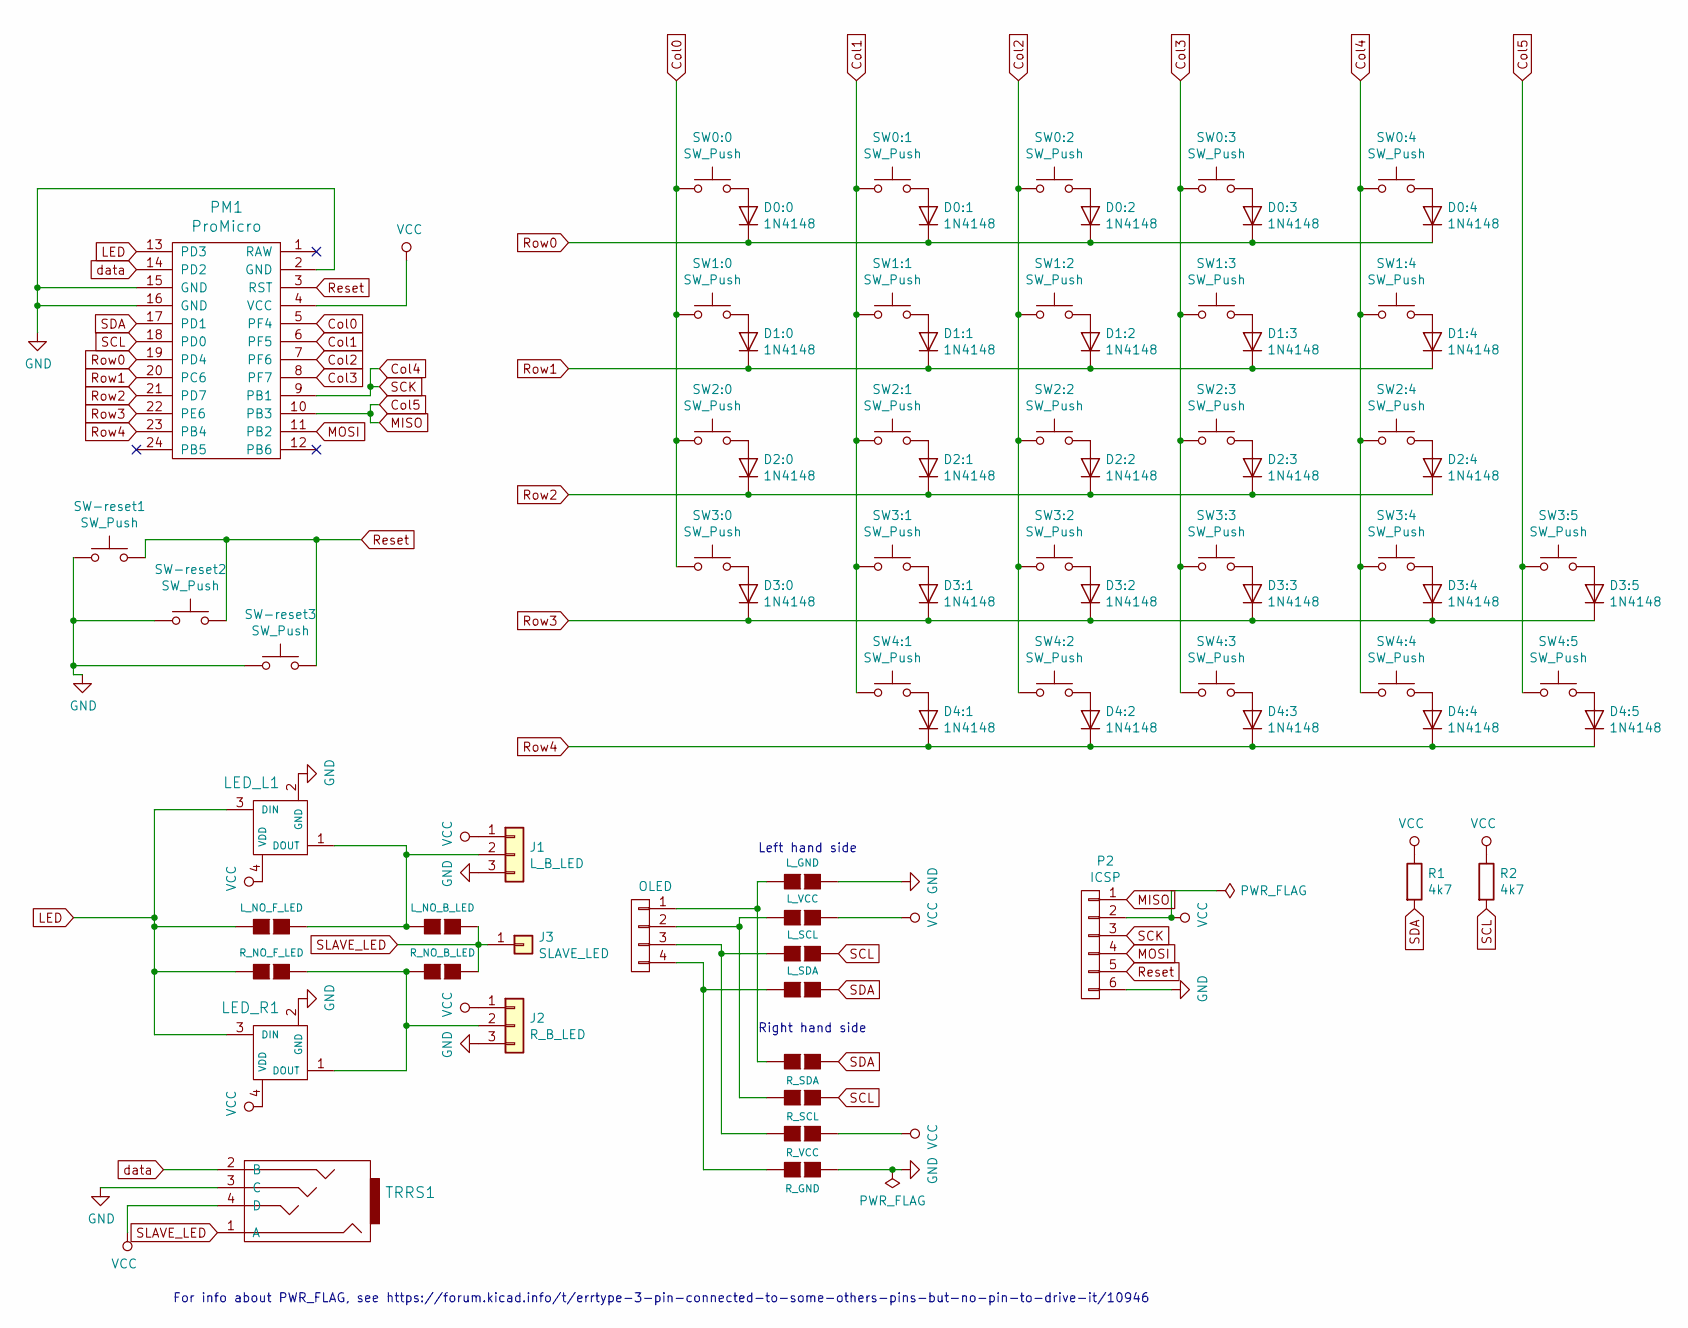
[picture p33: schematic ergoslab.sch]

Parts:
D0:0, D0:1, D0:2, D0:3, D0:4, D1:0, D1:1, D1:2, D1:3, D1:4, D2:0, D2:1, D2:2, D2:3, D2:4, D3:0, D3:1, D3:2, D3:3, D3:4, D3:5, D4:1, D4:2, D4:3, D4:4, D4:5: 1N4148; D_DO-35_SOD27_P7.62mm_Horizontal
J1: L_B_LED; ws2812-strip
J2: R_B_LED; ws2812-strip
J3: SLAVE_LED; PinHeader_1x01_P2.54mm_Vertical
JP1: L_GND; Jumper
JP2: L_VCC; Jumper
JP3: L_SCL; Jumper
JP4: L_SDA; Jumper
JP5: R_SDA; Jumper
JP6: R_SCL; Jumper
JP7: R_VCC; Jumper
JP8: R_GND; Jumper
JP9: L_NO_F_LED; Jumper
JP10: L_NO_B_LED; Jumper
JP11: R_NO_B_LED; Jumper
JP12: R_NO_F_LED; Jumper
LED_L1: SK6812mini; ws2812-single
LED_R1: SK6812mini; ws2812-single
P1: OLED; oled_header_helix
P2: ICSP; PinHeader_1x06_P2.54mm_Vertical
PM1: ProMicro; Pro_Micro_ergotravel
R1, R2: 4k7; resistor
SW0:0, SW0:1, SW0:2, SW0:3, SW0:4, SW1:0, SW1:1, SW1:2, SW1:3, SW1:4, SW2:0, SW2:1, SW2:2, SW2:3, SW2:4, SW3:0, SW3:1, SW3:2, SW3:3, SW3:4, SW3:5: SW_Push; Kailh_socket_reversible
SW4:1, SW4:2, SW4:3, SW4:4, SW4:5: SW_Push; kailh-choc-solder-reversible
SW-reset1: SW_Push; TACT_SWITCH_TVBP06
SW-reset2, SW-reset3: SW_Push; SW_TACT_ALPS_SKQGABE010
TRRS1: MJ-4PP-9; TRRS-helix

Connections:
Col0: PM1.5 (PF4), SW0:0.1, SW1:0.1, SW2:0.1, SW3:0.1
Col1: PM1.6 (PF5), SW0:1.1, SW1:1.1, SW2:1.1, SW3:1.1, SW4:1.1
Col2: PM1.7 (PF6), SW0:2.1, SW1:2.1, SW2:2.1, SW3:2.1, SW4:2.1
Col3: PM1.8 (PF7), SW0:3.1, SW1:3.1, SW2:3.1, SW3:3.1, SW4:3.1
Col4: P2.3, PM1.9 (PB1), SW0:4.1, SW1:4.1, SW2:4.1, SW3:4.1, SW4:4.1
Col5: P2.1, PM1.10 (PB3), SW3:5.1, SW4:5.1
GND: J1.3, J2.3, JP1.1 (G1), JP8.1 (G1), LED_L1.2 (GND), LED_R1.2 (GND), P2.6, PM1.2 (GND), PM1.15 (GND), PM1.16 (GND), SW-reset1.1, SW-reset2.1, SW-reset3.1, TRRS1.3 (C)
LED: JP9.2 (G2), JP12.2 (G2), LED_L1.3 (DIN), LED_R1.3 (DIN), PM1.13 (PD3)
MOSI: P2.4, PM1.11 (PB2)
unnamed: D0:0.2 (A), SW0:0.2
unnamed: D0:1.2 (A), SW0:1.2
unnamed: D0:2.2 (A), SW0:2.2
unnamed: D0:3.2 (A), SW0:3.2
unnamed: D0:4.2 (A), SW0:4.2
unnamed: D1:0.2 (A), SW1:0.2
unnamed: D1:1.2 (A), SW1:1.2
unnamed: D1:2.2 (A), SW1:2.2
unnamed: D1:3.2 (A), SW1:3.2
unnamed: D1:4.2 (A), SW1:4.2
unnamed: D2:0.2 (A), SW2:0.2
unnamed: D2:1.2 (A), SW2:1.2
unnamed: D2:2.2 (A), SW2:2.2
unnamed: D2:3.2 (A), SW2:3.2
unnamed: D2:4.2 (A), SW2:4.2
unnamed: D3:0.2 (A), SW3:0.2
unnamed: D3:1.2 (A), SW3:1.2
unnamed: D3:2.2 (A), SW3:2.2
unnamed: D3:3.2 (A), SW3:3.2
unnamed: D3:4.2 (A), SW3:4.2
unnamed: D3:5.2 (A), SW3:5.2
unnamed: D4:1.2 (A), SW4:1.2
unnamed: D4:2.2 (A), SW4:2.2
unnamed: D4:3.2 (A), SW4:3.2
unnamed: D4:4.2 (A), SW4:4.2
unnamed: D4:5.2 (A), SW4:5.2
unnamed: J1.2, JP9.1 (G1), JP10.2 (G2), LED_L1.1 (DOUT)
unnamed: J2.2, JP11.2 (G2), JP12.1 (G1), LED_R1.1 (DOUT)
unnamed: JP1.2 (G2), JP5.2 (G2), P1.1
unnamed: JP2.2 (G2), JP6.2 (G2), P1.2
unnamed: JP3.2 (G2), JP7.2 (G2), P1.3
unnamed: JP4.2 (G2), JP8.2 (G2), P1.4
Reset: P2.5, PM1.3 (RST), SW-reset1.2, SW-reset2.2, SW-reset3.2
Row0: D0:0.1 (K), D0:1.1 (K), D0:2.1 (K), D0:3.1 (K), D0:4.1 (K), PM1.19 (PD4)
Row1: D1:0.1 (K), D1:1.1 (K), D1:2.1 (K), D1:3.1 (K), D1:4.1 (K), PM1.20 (PC6)
Row2: D2:0.1 (K), D2:1.1 (K), D2:2.1 (K), D2:3.1 (K), D2:4.1 (K), PM1.21 (PD7)
Row3: D3:0.1 (K), D3:1.1 (K), D3:2.1 (K), D3:3.1 (K), D3:4.1 (K), D3:5.1 (K), PM1.22 (PE6)
Row4: D4:1.1 (K), D4:2.1 (K), D4:3.1 (K), D4:4.1 (K), D4:5.1 (K), PM1.23 (PB4)
SCL: JP3.1 (G1), JP6.1 (G1), PM1.18 (PD0), R2.2
SDA: JP4.1 (G1), JP5.1 (G1), PM1.17 (PD1), R1.2
SLAVE_LED: J3.1, JP10.1 (G1), JP11.1 (G1), TRRS1.1 (A)
VCC: J1.1, J2.1, JP2.1 (G1), JP7.1 (G1), LED_L1.4 (VDD), LED_R1.4 (VDD), P2.2, PM1.4 (VCC), R1.1, R2.1, TRRS1.4 (D)
data: PM1.14 (PD2), TRRS1.2 (B)

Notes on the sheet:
Right hand side
Left hand side
For info about PWR_FLAG, see https://forum.kicad.info/t/errtype-3-pin-connected-to-some-others-pins-but-no-pin-to-drive-it/10946

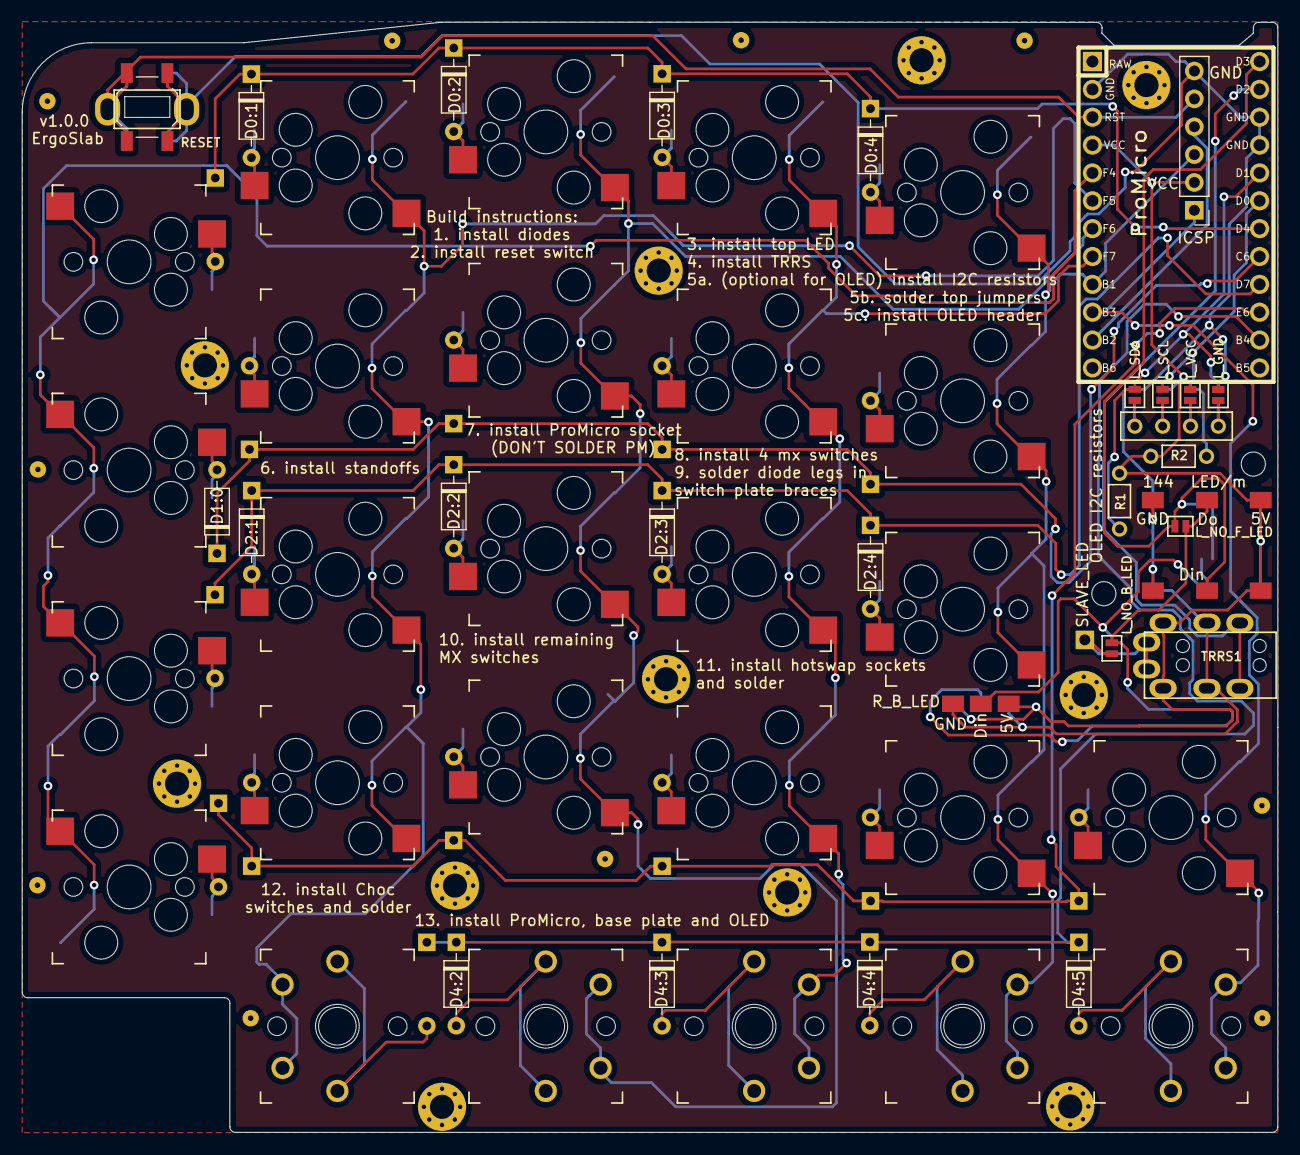
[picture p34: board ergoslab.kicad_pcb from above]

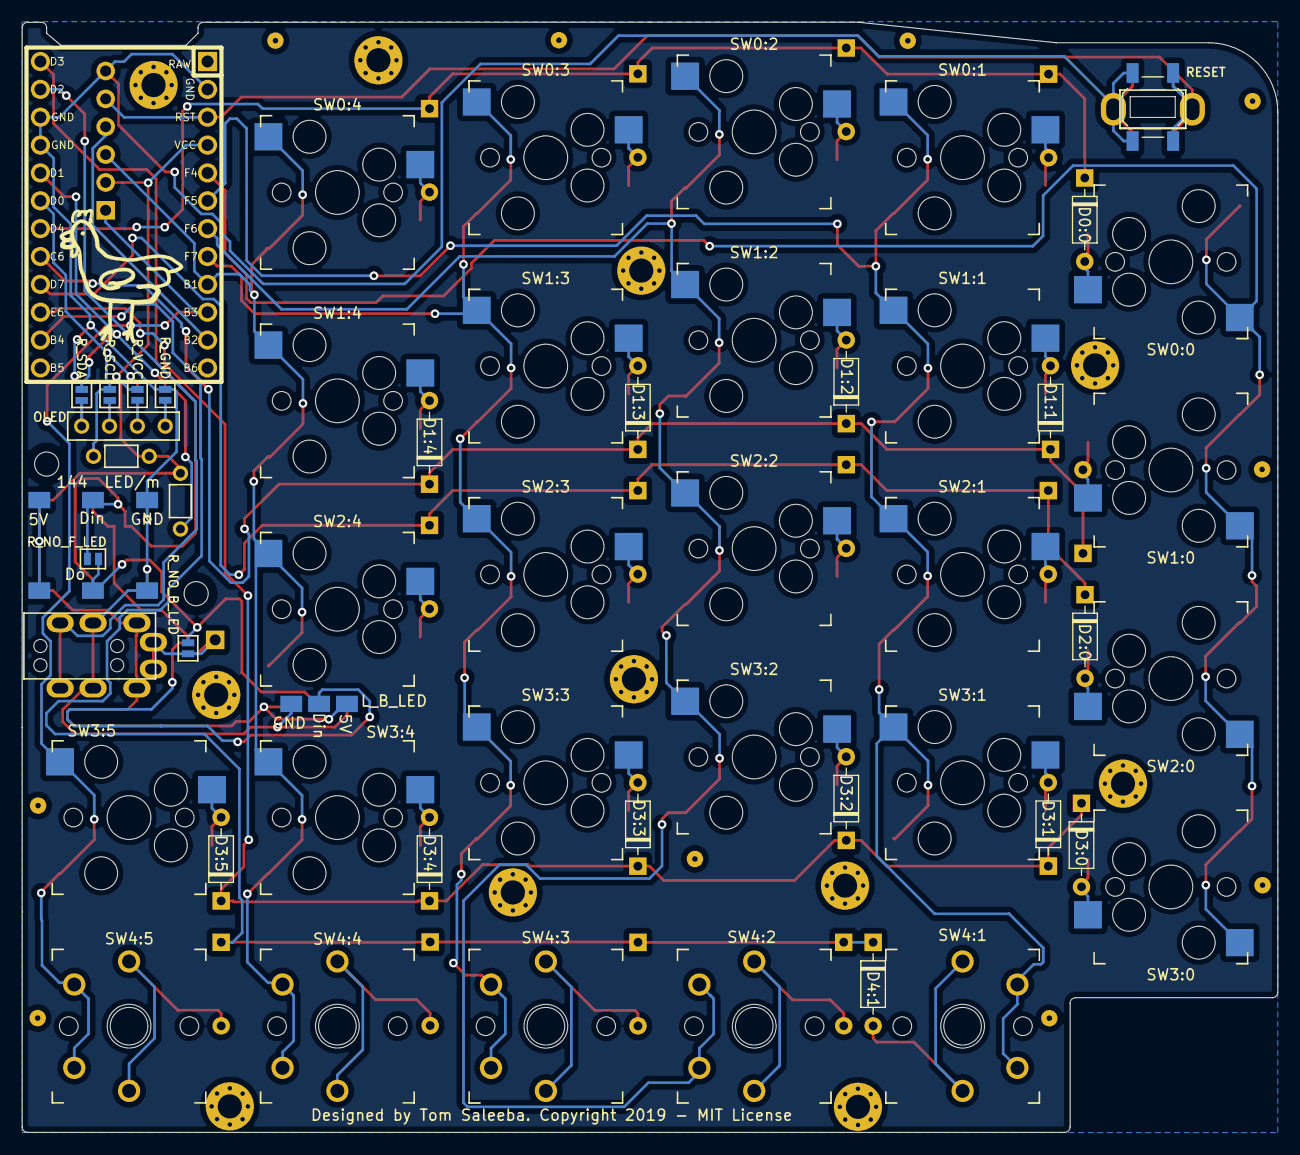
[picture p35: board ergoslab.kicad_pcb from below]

Board: 2 copper layers, 114.5 x 101.2 mm, 102 parts (24 on the bottom side), 52 nets.

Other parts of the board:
Brace0, Brace1, Brace2, Brace3, Brace4, Brace5, Brace6, Brace7: switchplate-brace
BraceNotTop0, BraceNotTop1: switchplate-brace
CHICKEN: LOGO; chicken
Mount0, Mount1, Mount2, Mount3, Mount4, Mount5, Mount6, Mount7: MountingHole_2.2mm_M2_Pad_Via
MountNotTop0, MountNotTop3, MountNotTop4: MountingHole_2.2mm_M2_Pad_Via
MountNotTop1, MountNotTop2: VAL**; HOLE_M2

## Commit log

2019-10-05 docs: mention method for using optional switch holes
2019-10-15 feat: remove seventh column of keys from main block and bring pro micro in closer
    [both.dxf, bottom.dxf, keyboard-layout-editor-config.txt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]
2019-10-22 feat: adjust thumb keys slighty to give more access to the middle one
    [keyboard-layout-editor-config.txt, master.dxf]
2019-10-27 chore: add POC, basic PCB
    [testy.kicad_pcb, testy.sch]
2019-10-27 chore: enlarged schematic to 4x4, fixed middle layer hole issue. Making a checkpoint before I try to get the netlist to update without destroying all my existing stuff
    [testy.kicad_pcb, testy.sch]
2019-10-27 chore: fixing some of the associations between the schema and pcb design. Still more to go
    [testy.kicad_pcb]
2019-10-28 docs: add todo list to test PCB
2019-10-28 feat: add reset switch and TRRS connector, test making promicro snapoff
    [testy.kicad_pcb, testy.sch]
2019-10-28 docs: add TACT switch part number
2019-10-28 feat: add all switches and LEDs to schematic
    [testy.kicad_pcb, testy.sch]
2019-10-29 fix: add idea for switch footprint that support choc solder in
2019-10-29 fix: get TRRS schematic to line up with footprint
    [testy.kicad_pcb, testy.sch]
2019-10-29 feat: more playing with layout
    [testy.kicad_pcb]
2019-10-30 chore: add some 4 pin reset switches, played with new footprints
    [testy.kicad_pcb, testy.sch]
2019-10-30 chore: add throwing star thumb tester DXF
    [switchplate.dxf]
2019-10-30 chore: revise throwing star layout, add helix stagger layout
    [switchplate.dxf]
2019-10-31 feat: remove footprint with solder on for fullsize MX switches, that wasn't ever going to work; fix existing combo footprint to add clearance for choc switches, start the col stagger layout
    [testy.kicad_pcb, testy.sch]
2019-10-31 feat: complete key layout
    [testy.kicad_pcb]
2019-10-31 chore: tidy up PCB, still lots of errors
    [testy.kicad_pcb]
2019-11-03 chore: fix misaligned edge cuts, remove some dupe components
    [testy.kicad_pcb]
2019-11-03 feat: some more layout
    [testy.kicad_pcb]
2019-11-06 feat: add perforations to pcb
    [testy.kicad_pcb]
2019-11-07 feat: try out moving left edge diodes to inner, tidy up edge cuts of bottom row, add edge connectors for moving thumb switch
    [testy.kicad_pcb]
2019-11-08 flipped left edge diodes, shrunk board a bit
    [testy.kicad_pcb]
2019-11-08 chore: add 100mm measurements
    [testy.kicad_pcb]
2019-11-09 feat: name all switches and diodes on PCB, still need to update refs
    [testy.kicad_pcb]
2019-11-10 feat: add all footprint refs, update netlist, do some wiring
    [testy.kicad_pcb, testy.sch]
2019-11-11 feat: wire up edge connectors
    [testy.kicad_pcb, testy.sch]
2019-11-11 feat: attempt to make usb-c breakout board footprint
    [testy.kicad_pcb, testy.sch]
2019-11-12 feat: another attempt at layout with the usb-c breakout board
    [testy.kicad_pcb]
2019-11-13 feat: add OLED and iCSP to schematic
    [testy.kicad_pcb, testy.sch]
2019-11-14 fix: updates related to copying helix underglow
    [testy.sch]
2019-11-15 chore: add dimension to the PCB to check something
    [testy.kicad_pcb]
2019-11-23 feat: add add new test layout with more little finger offset
2019-11-26 feat: move to new 5 col version
    [testy.kicad_pcb, testy.sch]
2019-11-29 feat: lots done, still need more LEDs, the I2C resistors and finish the traces
    [testy.kicad_pcb, testy.sch]
2019-11-30 feat: fully wired but stuff one side of the oled panels
    [testy.kicad_pcb, testy.sch]
2019-11-30 feat: fill in zones, add instructions, correct OLED jumpers on right(bottom), still need to finalise LED wiring
    [testy.kicad_pcb, testy.sch]
2019-12-02 fix: undo some wrong decisions with the LEDs
    [testy.kicad_pcb]
2019-12-02 fix: correct (I think) the LED wiring
    [testy.kicad_pcb, testy.sch]
2019-12-03 feat: create a choc-only footprint and use that for the bottom row, check that making the other switches MX only will remove DRC errors and it will, so that needs to be done. Also add choc reference 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
    [testy.kicad_pcb, testy.sch]
2019-12-03 feat: add back LED bypass jumpers
    [testy.kicad_pcb, testy.sch]
2019-12-03 feat: update all MX switches to MX-only footprint, still need to update edge cuts
    [testy.kicad_pcb, testy.sch]
2019-12-03 refactor: remove old stuff we don't need, move the PCB up, still more house keeping to go
    [both.dxf, bottom-ponoko.dxf, bottom.dxf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]
2019-12-04 fix: update edge cuts for MX switches, refresh PCB render
    [testy.kicad_pcb]
2019-12-05 refactor: house clean unused symbols and footprints, merge all symbols into one library, rename kicad project from testy to ergoslab
    [ergoslab.kicad_pcb, ergoslab.sch]
2019-12-05 feat: update chicken
    [ergoslab.kicad_pcb]
2019-12-05 fix: update single WS2812 footprint to be the correct size, still need to update the PCB
2019-12-06 docs: add list of parts to order
    [ergoslab.kicad_pcb]
2019-12-06 fix: update single WS2812 footprint on PCB, had to expand space allocated for ProMicro
    [ergoslab.kicad_pcb]
2019-12-06 fix: move dimensions off silk screen, change version 1.0=>0.1.0
    [ergoslab.kicad_pcb, ergoslab.sch]
2019-12-06 chore: update zone fills
    [ergoslab.kicad_pcb]
2019-12-10 docs: update readme with settings for generating gerbers
    [ergoslab.kicad_pcb]
2019-12-11 fix: increase all snap-off supports to at least 3mm as per JLCPCB requirements
    [ergoslab.kicad_pcb, ergoslab.sch]
2019-12-11 docs: add link to gerbers from README
2019-12-11 fix: test making switch plate cutout the correct size on SW4:4
    [ergoslab.kicad_pcb, ergoslab.sch]
2019-12-11 fix: make switchplate cutout for SW4:4 this time, last commit was actually SW3:4
    [ergoslab.kicad_pcb]
2019-12-11 fix: make all switchplate cutouts 14mm so switches will actually fit
    [ergoslab.kicad_pcb]
2019-12-15 chore: add refs for switchplate supports
    [ergoslab.kicad_pcb]
2019-12-15 feat: start creating python script to generate separate boards from the master board
    [base.kicad_pcb]
2019-12-15 fix: make sure edge.cuts remain on base layer, figure out how to read line width in python script
    [base.kicad_pcb]
2019-12-18 fix: generating something for all layers, outline is good, zones are refilled, still more to do
    [base.kicad_pcb, middle.kicad_pcb, top.kicad_pcb]
2019-12-19 feat: completed the new approach of generating PCBs from the master
    [base.kicad_pcb, ergoslab.kicad_pcb, ergoslab.sch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]
2019-12-19 chore: update pcb render
2019-12-19 docs: clarify required PCBs
2019-12-28 chore: bump version to 1.0.0 now I know it works (typing on it right now), give OLED resistor more space, make choc row M2 mounts more obvious, fix up silk screen build instructions
    [base.kicad_pcb, ergoslab.kicad_pcb, ergoslab.sch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]
2019-12-29 docs: add photo of layer LED in action
2019-12-30 docs: update build guide to talk about how to solder the jumpers
2020-01-02 docs: add note about hotswap sockets
2020-01-03 docs: add note about difficulty in getting PCB screw out through switch plate holes
2020-12-18 chore: add right plate vector for jhelvy/splitKbCompare tool
2022-02-03 docs: fix broken link to Kailh socket

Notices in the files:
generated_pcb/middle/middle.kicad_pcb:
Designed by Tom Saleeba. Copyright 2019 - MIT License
